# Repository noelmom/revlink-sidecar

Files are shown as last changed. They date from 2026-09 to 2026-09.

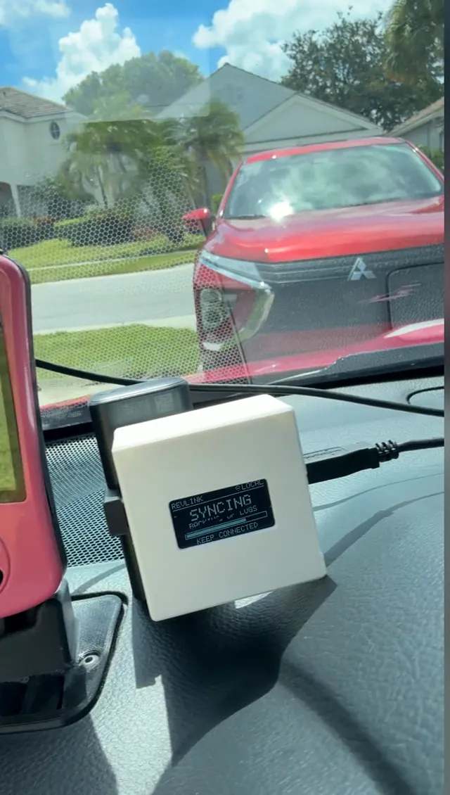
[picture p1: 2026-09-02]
web/site/assets/sidecar-sync-poster.webp

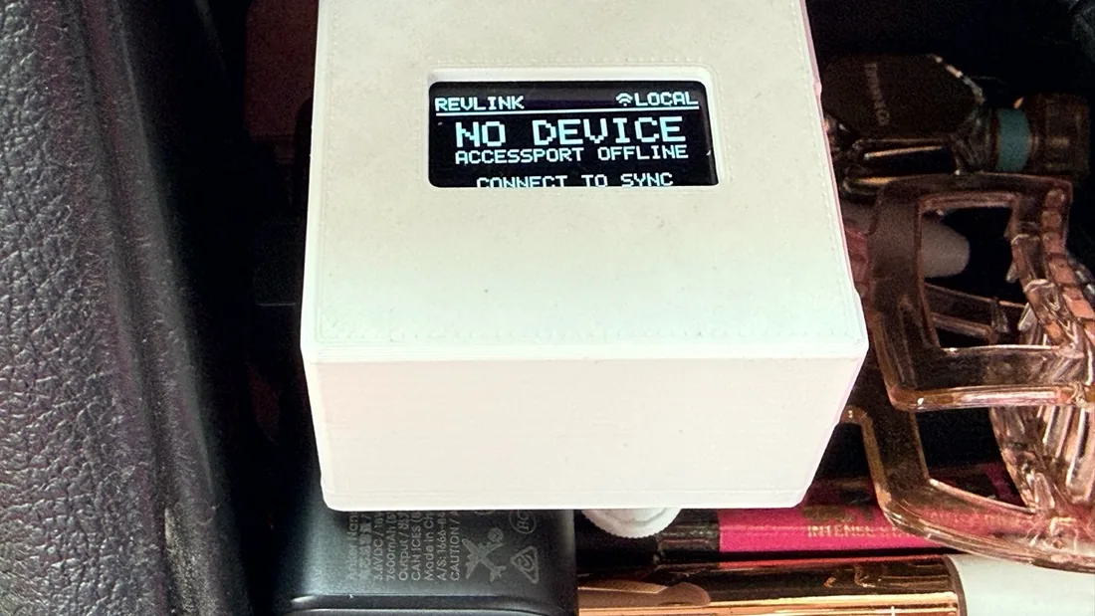
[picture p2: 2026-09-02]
web/site/assets/sidecar-oled.webp

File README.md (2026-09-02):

# RevLink Sidecar

**Use your AccessPort without a laptop.**

The COBB AccessPort stores your datalogs and maps over USB, but it only talks
to a Windows PC or a Mac. That means the moment you want to pull a log at the
track, at a meet, or in your own driveway, you need to go find a computer.

RevLink Sidecar is an ESP32-P4 that sits between the AccessPort and your
phone. Plug the AccessPort into the Sidecar, open a web page on your phone,
and your datalogs and maps are there — listed, downloadable, and graphable,
with no PC, no cloud account, and no internet connection.

Everything runs on the device. Your files land on a microSD card you own.

```
  AccessPort ──USB-A host──> ESP32-P4 Sidecar ──Wi-Fi──> your phone's browser
                                    │
                                 microSD
```

---

## What it does today

- **Automatic sync on attach.** Plug in the AccessPort and new datalogs and
  maps copy to microSD incrementally — only what changed.
- **Local web portal.** Served from the device itself. Joins your home or shop
  Wi-Fi when it can, and falls back to its own `RevLink-<id>` hotspot with a
  captive portal when it can't.
- **Datalog viewer.** Single and split views, numeric Y axes, searchable
  channels, reusable presets (Air/Fuel, Boost, Knock, Timing, Thermal),
  pointer inspection with exact values.
- **Vehicle Health.** A deterministic, local, rule-based evidence pass over
  logs you have already synced. No AI, no phone-home — it shows you the
  evidence it used.
- **Multi-device.** Keeps separate datasets per AccessPort, so a shop can
  service several cars without mixing files.
- **Stage a map without the device.** Save a `.ptm` while the AccessPort is
  unplugged; it is pinned to that car and survives a power cycle. Transfer it
  by hand when the device is next connected, or let it apply automatically
  after the next sync — that part is off until you turn it on.
- **Direct download and share.** Pull individual CSVs, or hand them to your
  phone's native share sheet.
- **OLED status.** Optional 1.3" SH1106 shows attach, sync, and network state
  at a glance.
- **Offline by design.** No account, no telemetry, no cloud dependency.

## What it deliberately does not do

This project reads and writes *files*. It is not a tuning tool.

- **No ECU flashing.** Not now, not planned.
- **No real-time tuning or live ECU writes.**
- **Map writes arrive locked** and stay off until you enable them. Copying a
  `.ptm` onto the AccessPort's storage is not the same as installing it — that
  remains a deliberate action on the AccessPort itself.
- **File deletion arrives locked too**, behind a *separate* switch from map
  writes — agreeing to one is never agreeing to the other. Only files directly
  inside `maps/` and `datalog/`, and there is no undo. See
  [SAFETY.md](SAFETY.md).
- **No public internet exposure.** The portal has no transport encryption and
  is meant for a trusted local network.

## Using it

One button does everything. On the Waveshare board it is `BOOT`; on the printed
case it is the left side button.

| Gesture | What it does |
| --- | --- |
| Double-press | Shows how to reach the portal — a Wi-Fi QR code when the Sidecar is running its own hotspot, or its `revlink-<id>.local` address when it has joined your network |
| Press again | Dismisses it |
| Hold 2 seconds | Safe shutdown: cancels work, unmounts the card, sleeps. `RST` or a power cycle wakes it |
| Two double-presses within 20 s | Authorises formatting a card that responded but would not mount — see [POWER_MANAGEMENT.md](docs/POWER_MANAGEMENT.md) |

The display gestures need the optional OLED. Everything else works without one.

## Hardware

| Part | Notes |
| --- | --- |
| Waveshare **ESP32-P4-NANO** | Primary target. USB-A OTG high-speed host, 16 MB flash, 32 MB PSRAM. [Buy][aff-nano] |
| Waveshare **ESP32-P4-WIFI6-DEV-KIT** (SKU 32054) | Supported, but build it yourself — no image is published for it. P4 revision 3.x silicon vs the Nano's 1.x, and the binaries are not interchangeable. |
| microSD card | Stores all synced files. Any capacity. [Buy][aff-sd] |
| 1.3" SH1106 OLED (optional) | SPI, not I2C. Status display. [Buy][aff-oled] |
| USB-C power bank | The reference build runs off an Anker Nano ([buy][aff-bank]). The Sidecar powers the AccessPort as a USB host, so give it a real 5 V supply — never source VBUS from a GPIO. |
| 3D-printed enclosure | [`hardware/nano-enclosure/`](hardware/nano-enclosure/) |

[aff-nano]: https://amzn.to/462r0q8
[aff-sd]: https://amzn.to/4h381C1
[aff-oled]: https://amzn.to/46BiJJQ
[aff-bank]: https://amzn.to/4gxIFfp

> **Affiliate disclosure.** The **Buy** links above are Amazon affiliate links.
> As an Amazon Associate I earn from qualifying purchases, at no extra cost to
> you. They point at the exact parts this was built and tested on, which is why
> they are here rather than a generic search. Buy them anywhere you like —
> nothing in this project depends on where the hardware came from.

**Why ESP32-P4 and not an S3?** The S3's native USB host is full-speed only,
and the AccessPort's 512-byte bulk endpoints require high speed. The S3 was
tried and retired — the full write-up is in
[`docs/ESP32S3_USB_POWER_BRINGUP.md`](docs/ESP32S3_USB_POWER_BRINGUP.md).

> [!NOTE]
> **Enclosure status.** This geometry has been printed and assembled — it is
> the case in the photos on [revlinkgarage.com](https://revlinkgarage.com/).
> The lid conceals the Ethernet jack, closes the
> donor case's switch slot and spare USB-A opening, and adds the centered OLED
> window plus two guided side buttons for RST and BOOT.
>
> One known refinement remains: the lid has **no internal mounting posts for
> the OLED**, so the display is retained by the window edge and its wiring.
> Adding four posts is a good first contribution — see
> [`hardware/nano-enclosure/tools/`](hardware/nano-enclosure/tools/) for a
> dependency-free way to verify a revision actually changed what you think it
> changed.

## Install

**Easiest — flash from your browser:
[revlinkgarage.com/flash](https://revlinkgarage.com/flash/)**

Open it in Chrome or Edge, plug the board in over USB-C, and click Flash. No
toolchain, no command line. It reads the board's silicon revision first and refuses to write an
image built for the other P4 variant.

The published image can read your AccessPort and, once you turn it on, copy a
`.ptm` map file back onto it. Writing arrives **locked**: you enable it in
Settings, only `maps/*.ptm` is accepted, and every write is read back and
checked against its SHA-256.

It can also delete files from `maps/` and `datalog/`, so a full AccessPort can
be cleared without a computer. That is a second switch, locked by default and
separate from writes, with no undo.

See [`web/flash/`](web/flash/) to host the page yourself.

## Build

Requires **ESP-IDF v6.0.2**, pinned in
[`firmware/esp32p4/idf-version.txt`](firmware/esp32p4/idf-version.txt).

```bash
source "$HOME/.espressif/frameworks/esp-idf-v6.0.2/export.sh"
```

Nano (P4 revision 1.x) — build in its own directory:

```bash
NANO_BUILD="$PWD/firmware/esp32p4/build-nano"
idf.py -C firmware/esp32p4 -B "$NANO_BUILD" \
  -D "SDKCONFIG=$NANO_BUILD/sdkconfig" \
  -D 'SDKCONFIG_DEFAULTS=sdkconfig.defaults;sdkconfig.oled.defaults;sdkconfig.wifi-scan.defaults;sdkconfig.wifi-join.defaults;sdkconfig.network-runtime.defaults;sdkconfig.onboarding.defaults;sdkconfig.nano.defaults' \
  set-target esp32p4 build
```

Do not flash a Dev Kit image onto a Nano. Full build and flash notes:
[`firmware/esp32p4/README.md`](firmware/esp32p4/README.md).

## Tests

The protocol, sync, storage, network, power, and safety logic are all built as
plain C11 with no ESP-IDF dependency, so they run on your laptop:

```bash
./scripts/ci-local.sh
```

That runs 19 host suites, 7 Node-based portal tests, the web flasher tests,
and the enclosure geometry baseline — about 20 seconds, and it needs only a C
compiler. If you don't have CMake, the script compiles the tests directly with
the same flags.

Add `--full` to also build the firmware three ways: writes enabled, deletion
compiled in, and writes compiled out. Building every configuration is what
catches code that only compiles under one of them. That needs ESP-IDF v6.0.2
plus CMake and Ninja.

```bash
./scripts/ci-local.sh --full
```

## Repository layout

```
firmware/
  esp32p4/          ESP32-P4 application, portal, storage, Kconfig, sdkconfig overlays
  components/       Platform-neutral C components (protocol, sync, network, status, …)
  test/             Host-side test suites — no hardware required
hardware/
  nano-enclosure/   3D-printable case: STL/3MF, source geometry, print notes
docs/               Architecture, safety model, networking, storage, bring-up
```

## Documentation

| Document | What it covers |
| --- | --- |
| [FIRMWARE_ARCHITECTURE.md](docs/FIRMWARE_ARCHITECTURE.md) | Component boundaries, device lifecycle, stable contracts |
| [SINGLE_ACCESSPORT_SAFETY.md](docs/SINGLE_ACCESSPORT_SAFETY.md) | Why two attached AccessPorts fail closed instead of guessing |
| [MAP_WRITE_ACCEPTANCE.md](docs/MAP_WRITE_ACCEPTANCE.md) | The gated round-trip procedure for map writes |
| [FILE_DELETE.md](docs/FILE_DELETE.md) | Removing a file from the AccessPort, and why it is gated apart from writes |
| [ACCEPTANCE_LOG.md](docs/ACCEPTANCE_LOG.md) | Dated bench records for the ESP32-P4 target. History, not current state |
| [FIRMWARE_UPDATE.md](docs/FIRMWARE_UPDATE.md) | How firmware gets onto the board, and why there is no OTA |
| [POWER_MANAGEMENT.md](docs/POWER_MANAGEMENT.md) | BOOT-button behaviour, safe shutdown, and deep sleep |
| [WIFI_BRINGUP.md](docs/WIFI_BRINGUP.md) | The ESP32-C6 radio link over SDIO, and what it took to bring up |
| [OLED_BRINGUP.md](docs/OLED_BRINGUP.md) | SH1106 wiring and the status screens |
| [ACCESSPORT_TIME_METADATA.md](docs/ACCESSPORT_TIME_METADATA.md) | What the AccessPort's timestamps mean, and what RevLink records instead |
| [ESP32S3_USB_POWER_BRINGUP.md](docs/ESP32S3_USB_POWER_BRINGUP.md) | Why the ESP32-S3 was retired: full-speed USB cannot do 512-byte bulk |
| [ESP32P4_DEMO.md](docs/ESP32P4_DEMO.md) | Runbook for demonstrating the Sidecar |
| [OPERATIONAL_LOGGING.md](docs/OPERATIONAL_LOGGING.md) | What is logged, what is not, and the two audit logs that ship |
| [STAGED_MAPS.md](docs/STAGED_MAPS.md) | Uploading a map with no AccessPort attached, and applying it on the next sync |
| [PRODUCT_NETWORKING.md](docs/PRODUCT_NETWORKING.md) | Client-first Wi-Fi with fallback hotspot and captive portal |
| [ACCESSPORT_STORAGE_BEHAVIOR.md](docs/ACCESSPORT_STORAGE_BEHAVIOR.md) | How the device's filesystem actually behaves |
| [SUPPORTED_ACCESSPORTS.md](docs/SUPPORTED_ACCESSPORTS.md) | Which hardware is verified, and how families are identified |
| [ACCESSPORT_CATALOG.md](docs/ACCESSPORT_CATALOG.md) | The part-number table: what it is, where it comes from, how to add to it |
| [VEHICLE_HEALTH.md](docs/VEHICLE_HEALTH.md) | The deterministic diagnostic layer |
| [SIDECAR_SD_BACKUP.md](docs/SIDECAR_SD_BACKUP.md) | Backing up and restoring the card |

## Status

Actively developed, and in regular use on a real car. Read-only sync (listing,
incremental download, checksum verification, atomic microSD publication) has
been accepted on real hardware, and so has writing: maps have been transferred
to an attached AccessPort many times, each verified by read-back, including
unattended transfers after a sync. Deletion is accepted too.

All three ship in the published image. Writes and deletes remain **gated** —
not because the paths are unproven, but because they are the owner's decision
to make. See [SAFETY.md](SAFETY.md) for exactly what is and is not proven.

## Contributing

Issues and PRs welcome — especially enclosure revisions, additional AccessPort
families, and portal UX. Please read [CONTRIBUTING.md](CONTRIBUTING.md) and
[SAFETY.md](SAFETY.md) first; this project touches hardware people depend on,
and the safety gates are not incidental.

## License

- Code (`firmware/`, scripts): **Apache-2.0** — [LICENSE](LICENSE)
- Hardware (`hardware/`): **CC BY-SA 4.0** — [LICENSE-hardware](LICENSE-hardware)

## Legal

RevLink Sidecar is an independent, unofficial project. It is not affiliated
with, endorsed by, or sponsored by COBB Tuning. "COBB" and "AccessPORT" are
trademarks of their respective owners and are used here only to identify the
hardware this project interoperates with. See [NOTICE](NOTICE).

Modifying your vehicle may affect its warranty, emissions compliance, and
legal road status in your jurisdiction. That is your responsibility. This
software is provided without warranty of any kind.

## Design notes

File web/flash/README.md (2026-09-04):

# Web flasher

A static page that flashes a RevLink Sidecar release over Web Serial. No
build step — plain HTML, CSS, and ES modules. Serve the directory over HTTPS
(or `localhost`) and it works.

```bash
python3 -m http.server 8777 --directory web/flash
```

It is self-contained and origin-relative, so the same directory can be
published on GitHub Pages, dropped onto revlinkgarage.com, or embedded in an
iframe.

## Layout

```
index.html                      markup and copy
style.css                       styling, light and dark
flash.js                        Web Serial + esptool-js driver
gate.js                         board-compatibility gate (no browser deps)
gate.test.mjs                   tests for the gate and the release manifest
vendor/esptool-js-0.6.1.js      vendored flashing library (Apache-2.0)
firmware/<release>/             binaries + manifest.json + SHA256SUMS
```

## Why the library is vendored

`esptool-js` is committed here rather than loaded from a CDN. This page writes
to people's hardware; a CDN that can substitute the script can substitute what
gets written. Vendoring also means the page keeps working offline and when a
CDN is blocked.

Upgrading it is deliberate: replace the file, bump the import in `flash.js`,
record the new SHA-256 below, and re-test against a real board.

```
esptool-js 0.6.1
sha256  ef7d5a237d3f273ecf546bcee65dddad90bd82cf02f22a980d1537e0cd79a152
```

## The board gate

The ESP32-P4-NANO and the ESP32-P4-WIFI6-DEV-KIT both report as `ESP32-P4`
but use pre-v3 and v3+ silicon, which ESP-IDF treats as mutually incompatible
firmware targets. `gate.js` reads the silicon revision and **refuses** a
mismatch before writing anything.

It fails closed. An unreadable revision, an unexpected chip family, or a
missing manifest field all refuse; only a positive match enables the button.
`gate.test.mjs` covers each case, and runs in `scripts/ci-local.sh`.

## Integrity

Every part is fetched, size-checked, and SHA-256 verified against
`manifest.json` before a byte reaches the board. A truncated download or a
tampered mirror fails before flashing, not halfway through it.

`gate.test.mjs` additionally verifies that the published binaries match their
recorded digests, that flash regions do not overlap, and that the image agrees
with what the manifest claims about device writes and deletes — by looking for
the corresponding log strings and NVS keys in the binary rather than trusting
the manifest's own flags, in either direction. A manifest that *under*-claims
fails too: people decide what to install from it.

It also asserts the shipping posture those flags imply — that a write-capable
image still declares consent locked at startup, and that a delete-capable one
carries its own separate consent key rather than riding on the write flag.

## Releases are immutable

```
releases.json                    {"current": "v0.2.6-nano"}
firmware/v0.2.6-nano/            binaries + manifest.json + SHA256SUMS
firmware/v0.2.5-nano/            the previous one, still reachable
```

A published release directory is never rewritten. A version string has to name
one set of bytes: if two different binaries both call themselves 0.2.0, a bug
report against 0.2.0 cannot be resolved, and someone comparing behaviour
between two boards has nothing to compare. Version 0.2.0 was overwritten
repeatedly while this repository was being built and was removed rather than
left as a false reference.

Publishing therefore *adds* a directory and moves the pointer in
`releases.json`. The page and the tests both read that pointer, so nothing has
to be edited in two places, and older releases stay reachable for anyone who
needs to go back to a build that worked.

`gate.test.mjs` enforces the parts of this that can be checked: the manifest
version must match the directory it lives in, and every release named in
`releases.json` must exist with digests that verify.

## Cutting a new release

```bash
# 1. Bump firmware/esp32p4/version.txt. Every published build gets its own
#    version; commits between publishes do not need one.
# 2. Build the profile you intend to publish.
source "$HOME/.espressif/frameworks/esp-idf-v6.0.2/export.sh"
B="$PWD/build-release/nano"
D='sdkconfig.defaults;sdkconfig.oled.defaults;sdkconfig.wifi-scan.defaults;sdkconfig.wifi-join.defaults;sdkconfig.network-runtime.defaults;sdkconfig.onboarding.defaults;sdkconfig.nano.defaults'
idf.py -C firmware/esp32p4 -B "$B" \
  -D "SDKCONFIG=$B/sdkconfig" -D "SDKCONFIG_DEFAULTS=$D" \
  set-target esp32p4 build

# 3. Copy the four artefacts into a NEW web/flash/firmware/<version>-<profile>/
#    as bootloader.bin, partition-table.bin, ota-data-initial.bin and
#    revlink-sidecar.bin. Never into an existing one.
# 4. Write its manifest.json and SHA256SUMS.
# 5. Add it to releases.json and set "current" to it.
# 6. Run ./scripts/ci-local.sh — the manifest, version and digest assertions
#    must pass.
# 7. Flash a real board before announcing it.
# 8. Re-check the docs against what you just flashed. See below.
# 9. Open a PR and MERGE IT WITH A MERGE COMMIT, not a squash. See below.
# 10. Tag the build commit, then cut a GitHub Release pointing at the release
#     directory on main.
```

### Re-check the docs against what you just built

Every sentence in the docs saying the firmware cannot do something is a claim
with an expiry date. Three have been wrong in public: the landing page said
writing maps was unproven on hardware while it was in daily use, `SAFETY.md`
said consent re-locks every boot when it persists in NVS, and
`WIFI_BRINGUP.md` listed a shipped network stack as future work.

This finds the sentences worth re-reading. It returns a short list, not a wall:

```bash
grep -rniE "not yet|has not been|have not been|is not implemented|\
remains unimplemented|not proven|future work|remaining work|\
not in the published|does not yet" \
  --include="*.md" --include="*.html" docs/ web/site/ *.md
```

Confirm each hit is still true of the build in the release directory, and fix
what is not in the same PR.

Check them against the tree or the binary, **never against another doc**. The
landing page's false claim was inherited from `SAFETY.md`, so a single stale
sentence propagated outward into the most public surface the project has.

Both directions matter, but they are not equally bad. Understating what
shipped is embarrassing. Overstating a safety property — or failing to notice
one has regressed — is not, and that is the direction this check exists for.

### Merge the release PR, do not squash it

`main` is protected, so a release goes through a pull request. Merge it with a
**merge commit**.

The binary embeds the commit it was built from — `CMakeLists.txt` resolves it
at configure time into `REVLINK_GIT_COMMIT`, it is what the portal footer
shows, and it is what `manifest.json` records as the provenance for those
bytes. A squash mints a new hash and discards the one that was built, so the
manifest ends up naming a commit that never reaches `main`. The release
directory then cannot be traced back to anything, which is the entire property
it exists to provide.

After merging, confirm it survived:

```bash
git merge-base --is-ancestor <build-commit> main && echo ok
```

### Tag the build commit, not the publish commit

```bash
git tag -a v0.2.6 <build-commit> -m "RevLink Sidecar 0.2.6 (v0.2.6-nano)"
git push origin v0.2.6
```

The tag names the commit whose source reproduces the published bytes. It
deliberately does **not** contain the release directory, which is added by the
commit after it — so a GitHub Release body must link the directory on `main`:

```
https://github.com/noelmom/revlink-sidecar/tree/main/web/flash/firmware/v0.2.6-nano
```

not at the tag, where it 404s. Release directories are immutable, so a link to
`main` is stable forever.

It is tempting to fix that by moving the tag onto the publish commit instead.
Do not. For 0.2.2 the embedded `portal/index.html` was corrected between the
build and the publish commit, so the publish commit does not rebuild the bytes
that were shipped. Tagging it would trade a broken link for a false provenance
claim, which is worse.

Offsets for the current partition table:

| Part | Offset |
| --- | --- |
| `bootloader.bin` | `0x2000` |
| `partition-table.bin` | `0x8000` |
| `ota-data-initial.bin` | `0xF000` |
| `revlink-sidecar.bin` | `0x20000` |

## Browser support

Web Serial is Chromium-only — Chrome, Edge, Opera, Arc, Brave. Safari and
Firefox do not implement it, and the page says so plainly instead of failing
mysteriously.

## Driver support

The Nano's programming console runs through an onboard WCH USB-serial bridge
(`1a86:55d3`). No driver is needed: confirmed on a clean Windows 11 machine and
on macOS, where the board enumerates on its own and flashes without anything
being installed first.

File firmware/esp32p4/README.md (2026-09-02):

# RevLink ESP32-P4 firmware

This target is the consumer-product hardware acceptance path for the Waveshare
`ESP32-P4-WIFI6-DEV-KIT` (SKU 32054) and `ESP32-P4-NANO`. They share the same
RevLink application and peripheral adapters but require separate binary builds
because the Dev Kit uses P4 revision 3.x silicon and the current Nano uses P4
revision 1.x silicon. Only the Nano has a published image; build the Dev Kit
yourself.

## Pinned environment

- Target: `esp32p4`
- ESP-IDF: `v6.0.2`
- Flash: 16 MB
- Stacked PSRAM: 32 MB, hex mode at 200 MHz
- Programming console: Type-C UART through the onboard WCH bridge
- AccessPort port: USB-A OTG 2.0 high-speed host, with the board's OTG jumper
  set to `HOST`

### ESP32-P4-NANO build

The Nano preserves the accepted RevLink prototype wiring:

- OLED: SPI2, CLK GPIO23, MOSI GPIO22, CS GPIO21, D/C GPIO20, RESET GPIO2;
- microSD: GPIO39 through GPIO44;
- ESP32-C6 Wi-Fi/BT link: SDIO GPIO14 through GPIO19, reset GPIO54; and
- AccessPort: onboard USB-A OTG 2.0 high-speed host.

The Nano overlay enables the SH1106 controller's 180-degree orientation for
the compact enclosure. Rendering stays in the shared framebuffer; the
board-specific overlay changes only the controller's segment and COM scan
directions.

Do not flash the Dev Kit's revision-3.x image onto the Nano. Build the Nano in
its own clean directory with the revision-1.x overlay:

```sh
source "$HOME/.espressif/frameworks/esp-idf-v6.0.2/export.sh"
NANO_BUILD="$PWD/firmware/esp32p4/build-nano"
idf.py -C firmware/esp32p4 \
  -B "$NANO_BUILD" \
  -D "SDKCONFIG=$NANO_BUILD/sdkconfig" \
  -D 'SDKCONFIG_DEFAULTS=sdkconfig.defaults;sdkconfig.oled.defaults;sdkconfig.wifi-scan.defaults;sdkconfig.wifi-join.defaults;sdkconfig.network-runtime.defaults;sdkconfig.onboarding.defaults;sdkconfig.nano.defaults' \
  set-target esp32p4 build
```

## Normal runtime and safety defaults

The normal build powers and enumerates the proven high-speed USB host, but it
does not start a file session unless the saved auto-sync preference is enabled
or the application receives an explicit manual request:

- `CONFIG_REVLINK_USB_ROOT_PORT_POWER` is enabled.
- `CONFIG_REVLINK_RUNTIME_SYNC` is enabled.
- `CONFIG_REVLINK_SYNC_AUTO_ON_ATTACH_DEFAULT` is disabled.
- `CONFIG_REVLINK_USB_INTERFACE_CLAIM_ACCEPTANCE` is disabled.
- `CONFIG_REVLINK_USB_ROOT_LIST_ACCEPTANCE` is disabled.
- `CONFIG_REVLINK_USB_DOWNLOAD_ACCEPTANCE` is disabled.
- `CONFIG_REVLINK_USB_INCREMENTAL_SYNC_ACCEPTANCE` is disabled.
- `CONFIG_REVLINK_ALLOW_DEVICE_WRITES` is enabled for guarded map transfer.
- `CONFIG_REVLINK_ALLOW_DEVICE_DELETES` is enabled in the Nano profile for
  guarded deletion inside `maps/` and `datalog/`.

The runtime coordinator exposes saved auto-sync policy, manual sync, progress
snapshots, and cooperative cancel to the embedded local API. Its bounded
read-only USB batch still permits at most four new files, 16 MiB per batch, and
8 MiB per file. A normal sync automatically opens clean continuation batches
until the complete safe inventory is verified or a batch makes no forward
progress. Guarded map transfer is available only after persistent owner
consent is enabled in Settings; new and factory-reset Sidecars default locked.
Startup-screen transfer uses the same guarded service and fixed framebuffer
target but still awaits its first live P4 write/read-back acceptance. Deletion
of files inside `maps/` and `datalog/` is compiled into the Nano profile from
0.2.2 and sits behind its own consent, separate from the write consent and
never implied by it.

The transport-neutral `revlink_control` service exposes those runtime
operations as status, auto-sync, manual-sync, and cancel commands. It returns
an immutable post-command snapshot and contains no HTTP, JSON, Wi-Fi, USB, or
storage implementation. The embedded portal's local HTTP adapter translates
requests into this contract rather than reaching into the USB stack.

The platform-neutral `revlink_usb_control` component is compiled into the P4
application and host-tested independently. The current P4 adapter does not
drive external GPIO because the isolation modules have not completed bench
bring-up. Do not assign USB control to GPIO39 through GPIO44; those pins are
reserved by the accepted microSD interface.

### Prototype status display

The optional `CONFIG_REVLINK_STATUS_OLED` adapter drives the existing
1.3-inch SH1106 SPI OLED. The screen shows the RevLink boot animation,
AccessPort availability, sync progress, recovery, completion, and actionable
fault states. Product state and copy come from the platform-neutral
`revlink_status` component; the SH1106 framebuffer and SPI transport remain a
replaceable P4 adapter.

Physical display acceptance passed on 2026-07-27: the splash and live status
rendered at the correct orientation and size while an attached AccessPort
advanced from inspection to ready state.

Use the reviewed prototype wiring in
[`OLED_BRINGUP.md`](../../docs/OLED_BRINGUP.md).
`sdkconfig.oled.defaults` is part of the shipped Nano fragment list, so the
published image includes this adapter; the panel itself is optional and the
firmware runs without one. To build the display overlay on its own:

```sh
source "$HOME/.espressif/frameworks/esp-idf-v6.0.2/export.sh"
idf.py -C firmware/esp32p4 \
  -B firmware/esp32p4/build-oled \
  -D SDKCONFIG=sdkconfig.oled \
  -D 'SDKCONFIG_DEFAULTS=sdkconfig.defaults;sdkconfig.oled.defaults' \
  set-target esp32p4 build
```

### Development UART control

The OLED bench overlay also enables `CONFIG_REVLINK_DEV_CONSOLE`. This
programming-UART adapter exercises the same transport-neutral control service
that future authenticated HTTP and BLE adapters will use:

```text
status
sync
cancel
auto on
auto off
help
```

The grammar is fixed and fail-closed. It has no command for device paths,
protocol opcodes, upload, delete, formatting, or arbitrary shell execution.
`auto on` and `auto off` update the saved automatic-sync preference; the
reviewed bench image is left with that preference off.

Live acceptance passed on 2026-07-27. A manual `sync` issued over the UART
selected the authoritative AccessPort namespace, reconciled 33 files as
verified cache hits, sent the polite subtype `0x05`, received subtype `0x35`,
and returned the re-enumerated device to `available`. A subsequent `status`
reported `completed`, progress `33/33`, auto-sync off, and writes locked. The
nonblocking console was also left idle for several seconds without prompt
repainting or interfering with enumeration.

### Development-board soft power

The Waveshare board's onboard `BOOT` button is GPIO35. After firmware boot, a
double press shows a full-screen Wi-Fi join QR when the RevLink hotspot is
active. When the Sidecar is already connected to a preferred Wi-Fi network,
the same double press shows its `revlink-<suffix>.local` browser address for
20 seconds instead. One additional short press dismisses either overlay.
The hotspot QR has a 30-second timeout and contains only the volatile
per-boot hotspot credential; generation is synchronous with the QR library's
input logging suppressed, and the payload is zeroized after its display
bitmap is captured. An active sync dismisses the URL overlay so transfer
safety status always wins.

The display also treats physical device state as newer than a terminal sync
result. Unplugging the AccessPort after a successful backup replaces
`<vehicle> / BACKUP COMPLETE / SAFE TO DISCONNECT` with
`NO DEVICE / ACCESSPORT OFFLINE / CONNECT TO SYNC`; a USB fault similarly
replaces stale completion with the attention view.

Once the read-only identity handshake has supplied the installed vehicle, the
ready view shows `<vehicle> / ACCESSPORT CONNECTED / READY TO SYNC`. Before
that authoritative identity is available, `ACCESSPORT` is used as the safe
headline fallback. The known vehicle is preserved through the expected
software re-enumeration after a clean session close, but is cleared for a
genuinely new physical attachment.

A two-second hold requests a demo-safe logical shutdown:

1. block new manual and automatic sync requests;
2. cooperatively cancel a queued or active sync and wait for a terminal state;
3. stop the logical USB root port;
4. abort any incomplete cache writer, release the selected device namespace,
   unmount the microSD card, and release its LDO; and
5. enter deep sleep.

Wake by pressing `RST` or cycling external power. `BOOT` is not configured as
a wake source on this development board.

This is a convenient prototype control, not physical power-off. The current
board cannot isolate USB D+/D- or VBUS in firmware. A properly initialized
session can return the AccessPort to Gauges by sending the polite subtype
`0x05`, receiving subtype `0x35`, and releasing the interface. An interrupted
or incomplete session may leave the AccessPort in PC mode, but a stale
read-only session has been recovered by reinitializing the complete session
and then performing the acknowledged polite close. The `revlink_usb_link`
board adapter still reports physical-isolation capabilities explicitly so an
optional future data/VBUS switch can be evaluated as defense in depth rather
than as the normal session-close path or a firmware dependency.

Idle-device live acceptance passed on 2026-07-27. With an enumerated
AccessPort and no active sync, the two-second hold blocked new work, disabled
the logical root port, produced a clean USB detach, unmounted and powered down
the microSD card, and entered deep sleep. Active-sync cancellation acceptance
remains pending.

## Architecture

The P4 firmware consumes platform-neutral components from
`firmware/components/`.
The protocol, lifecycle state machine, safety policy, and application
orchestration have no ESP-IDF dependency. The ESP-IDF USB host is an adapter
that emits normalized lifecycle events, and this target's `main/` directory is
the sole active firmware composition root plus the P4 SDMMC adapter.

See [`docs/FIRMWARE_ARCHITECTURE.md`](../../docs/FIRMWARE_ARCHITECTURE.md) for
the dependency rules and extension workflow.

## Build and flash

```sh
source "$HOME/.espressif/frameworks/esp-idf-v6.0.2/export.sh"
idf.py -C firmware/esp32p4 set-target esp32p4
idf.py -C firmware/esp32p4 build
idf.py -C firmware/esp32p4 \
  -p <your serial port> flash monitor
```

The first USB milestone is descriptor-only enumeration of VID/PID
`1a84:0121` at high speed with interface `0`, bulk OUT `0x03`, bulk IN `0x82`,
and 512-byte maximum packets. No proprietary request is permitted before that
gate passes.

## Hardware acceptance records

The dated bench records for this target — USB high-speed bring-up, microSD
coexistence with the onboard radio, incremental sync, multi-device safety,
session close, and guarded map transfer — are in
[`../../docs/ACCEPTANCE_LOG.md`](../../docs/ACCEPTANCE_LOG.md). They are
historical entries, not a description of the current build.

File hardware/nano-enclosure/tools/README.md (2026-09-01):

# Enclosure validation tools

## `stl_inspect.py`

Reports triangle count, bounding box, watertightness, and **genus** for a
binary STL. No dependencies — plain Python 3.

Genus is the useful number: it counts through-holes in a closed shell. Use it
to prove that a revision actually closed an opening rather than just
re-exporting the same geometry.

```bash
python3 stl_inspect.py ../enclosure-print/print-package/*.stl
```

Current baseline:

| Part | Genus | Meaning |
| --- | --- | --- |
| `source/esp32-p4-nano-bottom.stl` (donor) | 5 | Original case bottom |
| `01-…-nano-bottom.stl` (shipped) | 5 | Unchanged from donor |
| `source/esp32-p4-nano-top-solid.stl` (donor) | 6 | Original case lid |
| `02-…-top-oled-usbc-controls.stl` (shipped) | 3 | Revised lid — three openings closed |

### Measured bottom-shell openings

Sliced at z = 1.0 mm (the shipped `01` bottom, which is topologically
identical to the donor part):

| Wall | Span | Width |
| --- | --- | --- |
| Y− (`y = -2.5`) | `x` 3.0 → 18.0 | 15.0 mm |
| Y+ (`y = 52.5`) | `x` 19.7 → 27.1 | 7.4 mm |
| Y+ (`y = 52.5`) | `x` 32.0 → 40.0 | 8.0 mm |

The bottom is carried over from the donor case unchanged; the revised lid is
what conceals the Ethernet jack in the assembled enclosure. If you close or
reshape any of these bottom openings, the genus should drop accordingly —
that is the check this tool exists for.

Note that genus cannot see solid internal additions: adding the four OLED
mounting posts will raise the triangle count while leaving genus unchanged.
Check those visually in the slicer and against the physical display PCB.

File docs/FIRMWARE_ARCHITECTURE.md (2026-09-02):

# RevLink firmware architecture

The consumer firmware uses a layered, ports-and-adapters architecture. Board
SDKs and peripherals are implementation details at the edge; product rules
remain ordinary C that can run in host tests.

## Dependency direction

```text
esp32p4/main                         composition root
        |
        v
revlink_application   P4 hardware adapters
        | \ \          |-- accessport_usb (ESP-IDF USB Host)
        |  \ \         |-- P4 SD storage
        |   \ \        |-- P4 USB link control
        |    \ \       |-- P4 soft-power task
        |     \ \      |-- P4 SH1106 status display
        |      \ \     `-- P4 development UART
        v      v v
revlink_core  revlink_sync  accessport_protocol  revlink_power
                      \                 /
                       revlink_status  revlink_cli
```

Dependencies point inward. A core or application component must never include
ESP-IDF, FreeRTOS, USB, SDMMC, Wi-Fi, or board headers. An adapter may depend
on an inward contract and its platform SDK. Board `main/` code only selects
implementations, supplies configuration, and connects event callbacks.

## Current components

| Component | Responsibility | Platform dependency |
| --- | --- | --- |
| `accessport_protocol` | Capture-verified framing, parsing, checksums, and upload target validation | None |
| `accessport_catalog` | Exact-match supported-part catalog and family classification, without transport or feature side effects | None |
| `revlink_core` | Device lifecycle state machine and centralized operation authorization | None |
| `revlink_sync` | Incremental manifests/history plus the runtime sync coordinator and progress model | None |
| `revlink_power` | Debounce, long-press timing, and one-shot shutdown intent | None |
| `revlink_network` | Client-first/fallback-hotspot policy, sticky reconnect, time budgets, and transfer lock | None |
| `revlink_credentials` | Bounded Wi-Fi identity/password validation and explicit zeroization | None |
| `revlink_identity` | Persistent random Sidecar ID, MAC-derived local naming, and bounded collision suffixes | None |
| `revlink_staged_map` | Staged-map record codec and the pure decision function for applying one after a sync | None |
| `revlink_storage_recovery` | Guarded recovery state machine for a card that responds but does not mount | None |
| `revlink_oled_render` | 5x7 font, framebuffer primitives, and the boot splash layout, renderable on a host | None |
| `revlink_captive_dns` | Bounded DNS question parser and local IPv4 response encoder | None |
| `revlink_time` | Trusted/untrusted wall-clock classification and portable timestamp conversion | None |
| `revlink_update` | Bounded post-boot health decision, blocker reporting, and terminal ready/timeout/safety rejection | None |
| `revlink_usb_control` | Transport-neutral logical/electrical USB-link capabilities and safe control contract | None |
| `revlink_application` | Product-level initialization, protocol self-test, device/sync orchestration, and auto-sync policy | None |
| `revlink_control` | Transport-neutral local control commands and immutable status responses | None |
| `revlink_status` | Deterministic user-facing display state, progress, and copy derived from device/sync snapshots | None |
| `revlink_cli` | Fixed development command grammar and response formatting over the control contract | None |
| `accessport_usb` | ESP-IDF USB enumeration and normalized lifecycle events | ESP-IDF |
| `esp32p4/main/revlink_sd_storage` | P4 board SDMMC mount and accepted card layout | ESP-IDF/P4 |
| `esp32p4/main/revlink_usb_link` | Board-specific logical or physical AccessPort-link isolation | ESP-IDF/board |
| `esp32p4/main/revlink_soft_power` | GPIO polling and safe shutdown sequencing | ESP-IDF/P4 |
| `esp32p4/main/revlink_status_oled` | Optional SH1106 SPI framebuffer and status task | ESP-IDF/P4 |
| `esp32p4/main/revlink_dev_console` | Optional nonblocking programming-UART adapter for `revlink_cli` | ESP-IDF/P4 |
| `esp32p4/main/revlink_wifi_radio` | Bounded onboard ESP32-C6 acceptance adapter and identity-free radio snapshot | ESP-IDF/P4/ESP-Hosted |
| `esp32p4/main/revlink_network_runtime` | P4/C6 composition adapter for coordinator actions, RAM credentials, and transfer events | ESP-IDF/P4/ESP-Hosted |
| `esp32p4/main/revlink_onboarding` | Local HTTP setup, captive DNS/probes, mDNS, and delayed station transition | ESP-IDF/P4 |
| `esp32p4/main/revlink_portal` | Embedded product portal plus bounded status, inventory, cache streaming, notes, sync, cancel, and auto-sync HTTP adapters | ESP-IDF/P4 |
| board `main` | Hardware acceptance and dependency composition | Target board |

ESP32-P4 is the only active consumer-firmware target. Platform-neutral
components live in `firmware/components/`, and their host tests live in
`firmware/test/`. The former ESP32-S3 feasibility target is archived evidence
of the USB full-speed limitation; it is not built, maintained, or considered
when changing P4 contracts.

## Embedded product portal

The ESP32-P4 serves the product UI directly from firmware. It does not proxy
the laboratory application and does not require another computer after the
firmware is flashed. The current portal includes Dashboard, Datalogs, Maps,
Images, Device, Vehicle Health Beta, and Settings views plus a compact
five-item mobile navigation model.

The browser receives immutable cache projections and a deliberately small set
of bounded control/write adapters:

```text
GET  /api/portal/status
GET  /api/portal/devices
GET  /api/portal/files
GET  /api/portal/file?digest=<64-hex-sha256>
GET  /api/portal/backup
POST /api/portal/backup/preview
POST /api/portal/backup/restore
POST /api/portal/device/select
POST /api/portal/notes
POST /api/portal/log-map
POST /api/portal/sync
POST /api/portal/sync/cancel
POST /api/portal/auto-sync
POST /api/portal/time
POST /api/portal/writes
POST /api/portal/deletes
POST /api/portal/file/delete
POST /api/portal/maps/stage
POST /api/portal/maps/apply
POST /api/portal/maps/auto-apply
POST /api/portal/maps/discard
GET/POST /api/portal/startup/profiles
GET  /api/portal/startup/profile?id=<bounded-profile-id>
POST /api/portal/startup/apply
```

Map and startup-screen write routes remain inert until the compiled
administrator capability, persistent owner consent, one-device topology,
identity pin, exact target validator, and operation-specific confirmation all
agree. Deletion is exposed the same way, through `/api/portal/file/delete`
and `/api/portal/deletes`, behind its own consent.

`status.attachedAccessPort` is the live, read-only identity of the single
physically attached unit. `status.accessPort` is the independently selected
cached dataset retained for compatibility with the inventory projection. The
portal exposes this distinction as a global **Viewing data from** control:
switching it changes only the offline microSD projection and never redirects a
USB transaction, changes the OLED's connected-device identity, or writes to an
AccessPort.

`GET /api/portal/devices` scans only valid device namespaces whose stored
identity re-derives to the directory key. `POST /api/portal/device/select`
accepts one bounded key, requires the portal request header, and refuses to
switch while USB or synchronization work is active. The selector is responsive
and remains available on every product view, so mobile users do not need to
return to Dashboard to inspect another AccessPort's logs or maps.

The file route never accepts a path or filename. It resolves an exact digest
from the current portal snapshot, derives the object path from the selected
device namespace and known collection, then verifies the object is a regular
file with the manifest size before streaming it through a 4 KiB buffer.
Immutable objects remain valid if a later sync updates the current manifest.
Gzip-compressed datalogs retain their stored bytes and are served with
`Content-Encoding: gzip`, allowing the browser to parse the CSV without a
second decompression implementation in firmware.

The Datalogs and Maps libraries use Initial sync as their primary chronology.
Filename wrap and reuse therefore do not corrupt newest/oldest ordering.
Downloads are direct files rather than ZIP archives, and the selection bar
caps one user action at five files to keep mobile behavior predictable.
Notes remain version-scoped by SHA-256 on microSD.

The embedded log viewer parses quoted CSV locally and never sends vehicle data
off-device. It provides:

- Single and Split views;
- real numeric values and units rather than percentage normalization;
- shared-value and per-channel Y-axis modes;
- graph headroom above and below observed extrema;
- searchable channels and reusable browser-local profiles;
- Air/Fuel, Boost, Knock/Roughness, Timing, and Thermal split presets;
- pointer inspection with exact values;
- direct CSV download; and
- native OS sharing of up to five individual CSV attachments with a prepared
  subject/message and a download-plus-mailto compatibility fallback; and
- print-to-PDF using the browser's native print path.

Vehicle Health, guarded map/startup-screen writes, and native mail handoff are
local portal capabilities. Full in-browser email composition, Sidecar-hosted
delivery, accounts, share links, cloud sync, and AI analysis remain separate
product capabilities. Their absence must not cause the embedded portal to
imply that a remote service is available.

Account entitlements and billing policy do not belong in firmware. If an
optional hosted layer is ever added, a registered Sidecar may consume only a
signed, expiring capability snapshot with a bounded offline grace period. It
must never receive billing-provider identifiers, and local synchronization,
owned-data access, and export must keep working when no network is reachable.

## Stable contracts

The USB adapter reports `revlink_device_event_t`; it does not expose ESP-IDF
descriptor structures to the application. The core converts those events into
the deterministic lifecycle:

```text
stopped -> waiting -> inspecting -> available
                                     |       ^
                                     v       |
                                session-active
```

Detach returns an inspected or active device to `waiting`. Platform failures
enter `faulted`. Invalid transitions are rejected rather than guessed.

Before beta, the lifecycle must add a first-class `conflict` state for two or
more simultaneously live, accepted AccessPorts:

```text
waiting -> inspecting -> available
              |             |
              `-> conflict <-'
```

`conflict` blocks every device operation in both the application authorization
gate and USB adapter. The consumer UI never chooses between devices. The
current P4 adapter enumerates multiple addresses but its request loop still
selects the first accepted candidate, so this is an open safety gate rather
than an accepted capability. Transaction pinning, polite-re-enumeration
handling, recovery semantics, and the test matrix are defined in
[`SINGLE_ACCESSPORT_SAFETY.md`](SINGLE_ACCESSPORT_SAFETY.md).

`revlink_safety_policy_authorize()` is the mandatory operation gate.
Discovery and reads are allowed. Map writes, startup-screen writes, and device
deletes are denied by default. A transport implementation must not bypass this
application-layer decision even if it can physically submit a USB transfer.

## Channel separation

Do not create one oversized "AccessPort manager." Keep these channels
independent behind their own ports:

- file transactions on high-speed `0x03` OUT / `0x82` IN;
- live telemetry research on `0x02` OUT / `0x81` IN;
- local microSD repositories and manifests;
- Wi-Fi/BLE provisioning and connectivity;
- HTTP/API presentation;
- OTA and recovery;
- display/status output.

This prevents an experimental live-data decoder, a new storage backend, or a
different radio from destabilizing proven file synchronization.

### Supported-device classification

The exact supported-part catalog is isolated in `accessport_catalog`. It is
assembled from vendor-published product identifiers and contains 64 part
numbers across 12 protocol families; see
[`ACCESSPORT_CATALOG.md`](ACCESSPORT_CATALOG.md). USB eligibility, authoritative
device identity, reviewed part support, and feature capability remain separate
decisions:

1. `accessport_usb` validates the USB descriptors and reads the device's
   authoritative identity.
2. `accessport_catalog` matches the returned part number exactly.
3. The identity response remains authoritative for the installed vehicle;
   RevLink never guesses a vehicle from the catalog's broad compatibility
   list.
4. Read-only file work proceeds only for an exact reviewed part.
5. An unknown part remains visible for troubleshooting but fails closed before
   namespace selection, listing, or downloading.

The portal publishes the catalog revision, family, and read-only file-sync
capability for both the attached device and selected cached dataset. Catalog
membership does not grant live telemetry, map decoding, firmware work, upload,
or deletion. See [`SUPPORTED_ACCESSPORTS.md`](SUPPORTED_ACCESSPORTS.md).

## Firmware slots and recovery

The 16 MiB P4 flash is divided into an immutable 4 MiB factory recovery image,
two 4 MiB OTA slots, redundant OTA selection data, NVS/PHY state, and a bounded
crash partition. ESP-IDF rollback support is compiled into the bootloader, but
no network update route exists yet. A future update service must write only the
inactive OTA slot and mark a pending image valid only after the bounded product
health gate passes. The partition contract and security gates are documented
in [`FIRMWARE_UPDATE.md`](FIRMWARE_UPDATE.md).

## Peripheral ownership and build profiles

The Waveshare development board exposes one P4 SD/MMC host to both its
onboard ESP32-C6 link and its microSD wiring. Resource ownership is therefore
selected at build time:

```text
default:
    SD/MMC -> microSD (4-bit)
    C6 radio -> disabled

wifi-scan:
    SD/MMC -> ESP32-C6 (4-bit SDIO)
    SPI3   -> microSD
```

The display remains on SPI2 and AccessPort traffic remains on the independent
high-speed USB host in both profiles. The storage port above FAT and the sync
coordinator do not know whether the card uses SDMMC or SPI; switching the
board adapter cannot change namespaces, manifests, immutable-object rules, or
transaction limits.

Managed-component presence is not authority to start hardware. The default
configuration explicitly disables `ESP_WIFI_REMOTE` and `ESP_HOSTED`, and the
radio source compiles its ESP-IDF Wi-Fi path only when the bounded profile is
selected. Both radio-off and radio-on images must build in CI. This prevents a
dependency update from silently claiming the SD/MMC controller.

The radio adapter supports an explicitly requested anonymous station scan, one
station connection, and one RAM-only WPA2 fallback SoftAP. It owns the ESP-IDF
station/AP netifs, hosted-radio mode changes, association events, AP client
count, and generated device SSID. It starts no HTTP server and persists no
credential itself. The independent `revlink_wifi_store` adapter owns the one
preferred station record; the network runtime saves it only after association
succeeds and loads it before the coordinator starts.

The platform-neutral `revlink_network` coordinator owns the product policy
above that adapter. It selects actions for saved-network scanning, one opaque
preferred-network connection, bounded same-network reconnect, and fallback
hotspot startup. While client-ready it schedules bounded local-link probes,
filters transient failures, and requests radio recovery after three
consecutive failures. It never handles an SSID, password, netif, ICMP packet,
or BLE packet.
Automatic background migration is intentionally absent, so a successful
lower-priority connection remains sticky until it is lost. HTTP, BLE, and
physical recovery controls will emit coordinator events rather than switching
the radio directly.

`revlink_network_runtime` is the P4 acceptance composition adapter between
those two layers. It converts coordinator actions into radio calls, hashes a
station identity into an opaque policy ID, ticks bounded timeouts, and reports
radio loss upward. It probes only the DHCP gateway, pauses probes during file
transfers, restarts the hosted radio on sustained failure, and applies a
one-reboot guard if both station and hotspot recovery are exhausted. It owns
only acceptance-time RAM credentials.
`revlink_credentials` centralizes their bounds and zeroization, while
`revlink_onboarding` translates bounded local HTTP requests into the same
runtime operation. Its captive DNS parser remains platform-neutral and does
not own sockets. The future encrypted credential repository remains a
separate port because selecting flash encryption or HMAC/eFuse provisioning
is an irreversible product-security decision. Sync terminal and start events
drive the coordinator's transfer lock so user-requested network mode changes
cannot interrupt an active file operation. The composition root asserts that
lock as soon as sync state becomes `queued`, keeps it asserted through
`running` and `cancelling`, and clears it only on a terminal state. The P4
runtime setter is idempotent so progress callbacks cannot generate redundant
policy events. Live acceptance rejected a mode transition submitted
immediately after queueing while allowing the read-only sync and acknowledged
AccessPort close to finish normally.

## Local control boundary

HTTP, BLE, a future display, and test tooling must not call USB or storage
adapters directly. They translate their input into the same platform-neutral
`revlink_control_request_t` command and receive a
`revlink_control_response_t` containing the current device, sync, policy, and
capability snapshot.

The accepted commands are status, saved auto-sync policy, manual sync, and
cooperative cancellation. Unknown commands fail closed. Mutating commands
also return the resulting snapshot so a UI does not need to guess whether its
request took effect. The ESP32-P4 composition root maps these commands onto
the runtime application. The portal's HTTP/JSON adapter, which ships, owns
serialization, request-size limits, and task serialization on top of it.

The optional development UART is the first concrete input adapter for this
boundary. `revlink_cli` accepts only `status`, `sync`, `cancel`, `auto on`,
`auto off`, and `help`; it cannot accept a path, protocol opcode, write, or
delete request. The P4 adapter incrementally reads printable characters from
the programming UART and never blocks the USB or display tasks waiting for a
line. This interface is bench tooling, not a product authentication boundary.

Output-only status surfaces subscribe to immutable lifecycle and sync
snapshots. `revlink_status` converts those snapshots into a small semantic
view—headline, detail, footer, severity, and progress—without knowing which
screen renders it. A monochrome OLED, future color display, LEDs, and an HTTP
status stream can therefore share product behavior without sharing a display
driver. Active sync/cancellation and reconnect safety messages have the
highest priority. After those states, current physical device absence or USB
fault takes priority over a prior terminal sync result so the display cannot
claim a completed backup indefinitely after the AccessPort is removed.

## Idle vehicle behavior and USB isolation

Controlled ESP32-P4 tests on 2026-07-26 proved that USB VBUS, high-speed
enumeration, and a complete descriptor scan do not by themselves put the
AccessPort into PC mode; Gauges remain available. ESP-IDF can then disable the
logical root port and report a clean host disconnect. This descriptor-only
result repeated after a clean P4 reboot.

Follow-up tests on 2026-07-26/27 proved that the session state preceding the
disconnect request is significant. A cold combined lifecycle test that never
established identity left the AccessPort on `connected to your computer`
after interface release and logical root-port shutdown. An isolated test that
sent only the capture-verified mini subtype `0x05` also produced no
subtype `0x35` acknowledgment, software re-enumeration, or return to Gauges.

A complete read-only session passed software-only exit acceptance on
2026-07-27. The P4 completed the identity handshake, listed and reconciled 33
datalogs against the per-device microSD manifest, sent subtype `0x05`, received
the expected subtype `0x35` acknowledgment, and released interface `0` with
`ESP_OK`. The AccessPort performed a software detach/re-enumeration and visibly
returned to Gauges while D+/D- and VBUS remained connected. The P4 classified
the new attachment as a polite software re-enumeration and did not start a
second transaction. The same scheduler subsequently accepted a combined
33-datalog/one-map inventory without changing this lifecycle.

The same lifecycle then passed five consecutive automated cycles. Every cycle
reconciled the same 33-file namespace, produced an acknowledged `0x05`/`0x35`
close, released interface `0` with `ESP_OK`, observed removal, and accepted a
fresh high-speed address before scheduling the next cycle. No cable action,
manual D+/D- switch, logical root-port shutdown, bus reset, or VBUS removal
was used.

Therefore the normal exit path is a polite subtype `0x05` close after a
successfully initialized session, followed by interface release. Logical
root-port shutdown and an unacknowledged or context-free subtype `0x05` remain
insufficient.

Do not automatically issue `SET_CONFIGURATION(0)` or a host-side bus reset
after the acknowledged close. Research proposed those as workarounds for a
missed soft disconnect, but the live P4 trace disproved that premise: ESP-IDF
reported the removal and re-enumeration on every accepted cycle. Preserve the
device-originated removal as lifecycle evidence instead.

A stale read-only PC-mode session was subsequently recovered by rebooting and
reinitializing the P4 host, completing the full bounded handshake, sending
subtype `0x05`, receiving subtype `0x35`, and releasing the interface. The
AccessPort returned to Gauges without opening D+/D- or removing VBUS.

The same recovery was then accepted under deterministic fault injection
without rebooting. Firmware deliberately omitted the first close after a
completed 33-file read-only reconciliation. The application queued one
dedicated recovery (never a second data sync), deferred it until the original
USB work item released the device, attempted the normal initialized identity
probe, and then issued the bounded close. Although the probe timed out against
the stale session, `0x05` received `0x35`; interface release succeeded, and
the AccessPort removed and re-enumerated at a fresh high-speed address.
Recovery success is therefore `acknowledged close + clean release`, while the
original sync retains its independent `data phase complete` evidence.

The retry budget is one per explicit or attachment-triggered sync. It is
eligible only when the original read-only data phase completed but its close
was not acknowledged. Data-phase failures, cancellation, write paths, and a
failed recovery do not recurse.

Software recovery is consequently the required primary path. A
GPIO-controlled reverse-blocking VBUS switch and high-speed data-path switch
with a true disabled state remain optional final-product defense in depth,
pending interrupted-transfer, timeout, repeated-cycle, crash, and write-fault
testing. Do not add unconditional VBUS discharge: an OBD-powered AccessPort
can hold the downstream node at 5 V and RevLink must not sink that external
supply.

### Safe shutdown boundary

The demo firmware reuses GPIO35/`BOOT` after boot as an active-low physical
control. The platform-neutral `revlink_power` component owns debounce and
reports short-release or long-hold intent. The P4 adapter maps a double press
to a context-aware network shortcut: the bounded, volatile Wi-Fi QR in local
hotspot mode, or the bounded `.local` browser address in preferred-network
mode. A single press dismisses either overlay. The URL overlay is unavailable
during active transfer work and is dismissed if sync begins or the preferred
network drops. A two-second hold maps to soft power. The P4 adapter owns the
shutdown side effects:

```text
block new syncs
    -> disable in-memory auto-sync
    -> cooperatively cancel active work
    -> wait for a terminal sync state
    -> isolate the board USB link as far as hardware permits
    -> abort incomplete storage work and unmount microSD
    -> deep sleep
```

If cancellation does not become quiescent within 30 seconds or the card
cannot unmount, firmware remains awake rather than risking an interrupted
transaction. The current Waveshare link adapter advertises no physical data
or VBUS isolation and performs logical root-port shutdown only. A custom-board
adapter may implement physical isolation without changing the power-button,
sync, or storage components.

The read-only file pipeline itself is now proven end to end. On 2026-07-26,
the ESP32-P4 issued one bounded `datalog` listing request, parsed 33 entries,
selected `datalog35.csv`, and streamed one download through the incremental
archive decoder into the atomic microSD cache sink. The sink published only
after exact-size and SHA-256 validation:

```text
46568 bytes
bff4f73f8aef276d354c8277bdc6547433f6f15a164ba41ebe2df1ff736e2688
```

This matches the Linux acceptance baseline byte for byte. An identical
existing cache entry was deduplicated. No retry, upload, delete, live-data,
reset, or disconnect transaction was sent. This validates the replaceable
protocol-decoder, USB-source, and storage-sink boundaries, but it does not
remove the separate requirement for drive-idle electrical isolation.

The next read-only gate promoted that path to bounded incremental sync. A
platform-neutral manifest component now owns file identity and serialization;
the ESP32-P4 SDMMC adapter owns durable publication and cache verification;
and the USB adapter owns one-session scheduling limits. The manifest records
device path, raw device timestamp, size, SHA-256, local cache name, and the
trusted UTC time when that exact version was first synchronized. A candidate
is skipped only after both metadata and the actual cached file verify.
Manifest v2 preserves that first-sync value across reconnects. Parsing remains
backward compatible with manifest v1; migrated entries use zero rather than
inventing a date.

The `revlink_time` component owns the replaceable UTC anchor. The P4
composition may initialize it from network time, a plausible retained RTC, or
the local browser clock when no stronger source exists. HTTP does not write
manifest fields directly: it submits a bounded time observation through the
time-service adapter. When UTC first becomes available, the storage adapter
repairs only zero-valued Initial sync fields for the last unambiguous device
namespace. Nonzero values remain immutable. A supported rechargeable RTC
battery is still required to retain accurate time through a complete
unattended power loss.

Editable user annotations are deliberately stored outside both authoritative
sync documents. `revlink_sync_annotations` keys each note by the cached
content's SHA-256 inside that AccessPort's namespace. A note therefore follows
identical bytes across a rename, does not leak to replacement content when a
native filename rotates, and cannot make a valid sync manifest unreadable.
Notes support multiline UTF-8 text up to 767 bytes. Their update time is zero
while wall-clock time is untrusted and UTC only after the time service has a
trusted source. The platform adapter must publish changes using the same
temporary-file, `fsync`, backup, and atomic-rename pattern as manifests.

The FAT adapter uses `current`, `.tmp`, and `.bak` manifest files because FAT
rename cannot atomically replace an existing destination. Data publication
still precedes manifest advancement, so an interruption can leave a safe
unindexed file but cannot create a manifest entry for incomplete data. On the
physical board, an interrupted run resumed from one valid entry, deduplicated
the already completed next file, and advanced to five entries. A reset then
loaded those five entries, verified and skipped all five, and downloaded the
next four. The two accepted bounded sessions reported `4 downloaded / 1
skipped` and `4 downloaded / 5 skipped`, respectively, and both released the
interface cleanly with writes disabled.

### Multi-device identity and immutable file history

Persistent data is never keyed by the USB descriptor serial. The connected
AccessPort exposes the placeholder
`0123456789.0123456789.0123456789`; the file session therefore sends the four
capture-verified read-only identity mini requests and parses the third
`0x1601` response before storage can be selected. A sync fails closed if the
true serial cannot be obtained or if a namespace's stored identity disagrees.

The storage key is the first 24 lowercase hexadecimal characters of
`SHA-256("revlink-device-v1:" + true_serial)`. Every AccessPort owns a
completely separate directory:

```text
/revlink/devices/<device-key>/
  identity.txt
  annotations.tsv
  current/inventory.manifest
  history/inventory.versions
  objects/datalogs/<full-sha256>.csv[.gz]
  objects/maps/<full-sha256>.ptm
  tmp/
```

The `current` manifest answers “what bytes are currently observed at this
remote path?” while the append-only version journal answers “what bytes have
ever been observed at this path?” Object names are content-addressed by the
full SHA-256, so AccessPort filename rotation cannot overwrite an older log
or map. The remote path—including its `datalog/` or `maps/` collection—is the
authoritative manifest key. Equal filenames in different collections cannot
collide.

### Diagnostic map context

A diagnostic case may optionally reference the map used while its evidence
logs were recorded. The reference is an immutable snapshot containing the
device-scoped map path, full content SHA-256, byte size, initial-sync time, and
available device timestamp metadata. A filename alone is never sufficient:
AccessPort files can be replaced under the same name, and a later replacement
must not silently change an existing case.

The future tuning-summary engine attaches its own versioned result to this
snapshot. It may describe a change only when both the selected map and an
explicit baseline are available through a parser with verified provenance.
Opaque PTM bytes, a filename such as `stage2`, or tuner-supplied timestamps
must not be converted into guessed table or calibration changes. Until those
requirements are met, the UI shows the verified map identity without claiming
a tuning summary.

The commit order is object, version history, then current manifest. A power
loss may leave a safe orphan object or an already-recorded history entry, but
cannot make incomplete bytes current. Both journals use the FAT-safe
`current`/`.tmp`/`.bak` publication pattern and recover an interrupted
publish.

The portal's offline projection is also independent of the Sidecar network
identity. `/revlink/last-device` is a small versioned, FAT-safe pointer to the
last AccessPort namespace selected by an authoritative identity handshake.
At boot, the adapter verifies that namespace's `identity.txt`, re-derives its
key from the stored true serial, then loads the current manifest and notes for
read-only portal display. It immediately releases session selection, so a
later USB operation cannot inherit writable state from the cached projection.

For cards created before this pointer existed, the migration selects a device
only when exactly one valid namespace is present. Multiple namespaces without
a pointer are intentionally ambiguous: the portal waits for a real sync
instead of merging data or guessing which device is current. Changing the
Sidecar hostname, SSID, collision suffix, or internal `r1_...` ID therefore
cannot orphan or re-key AccessPort data.

When one eligible AccessPort is attached, the runtime automatically queues an
identity-only work item after enumeration unless a full auto-sync is already
queued or running. It executes the same four capture-verified read-only
identity mini requests and acknowledged `0x05`/`0x35` close as a full sync,
but does not list or download files. This establishes
`attachedAccessPort` immediately and creates/selects the correct empty
namespace for a previously unseen unit. A polite software re-enumeration
preserves that live identity; a genuine physical detach clears it. The user
may subsequently select a different cached namespace for browsing without
changing the attached identity.

The unified ledger names supersede the original datalog-specific filenames.
On upgrade, the storage adapter atomically adopts the legacy primary manifest
and history files only when their unified destinations do not exist. Live
acceptance after reset loaded all 34 pre-upgrade entries, SHA-verified and
skipped all 33 datalogs plus one map, transferred zero bytes, and left writes
disabled.

This architecture was accepted live on the ESP32-P4 on 2026-07-26. The board
read true serial `SUB0406661`, selected device key
`d2313ecdf618801b8d5b1270`, SHA-verified four existing immutable objects, and
downloaded four more. After reset it loaded eight current/history entries,
verified and skipped all eight, and downloaded the next four. The sessions
reported `4 downloaded / 4 skipped` and `4 downloaded / 8 skipped`; both
released interface 0 with `ESP_OK`, and all write/delete capabilities remained
disabled. The board was then restored to its normal descriptor-only firmware.

### Attachment-scoped session lifecycle

Sync eligibility belongs to an enumerated physical attachment, not to the
firmware boot. A newly accepted USB device record may run one bounded session.
When that session ends, the USB adapter releases interface `0` and tells the
storage adapter to abort any active writer, clear its in-memory manifests and
history, and forget the selected device namespace. A detach destroys the USB
record. A subsequent attach therefore re-reads authoritative identity and may
run another bounded session without rebooting.

This prevents three classes of cross-session error:

- a reconnect cannot be blocked by a boot-global “already synced” flag;
- a replacement AccessPort cannot inherit another device's manifest; and
- a failed or unplugged transfer cannot leave a writable temporary object
  selected for the next session.

The same-device reconnect path passed live on 2026-07-26. The first attachment
loaded 16 entries, downloaded four, and released at 20. After physical
unplug/replug, the unchanged firmware accepted the new USB address, re-read
serial `SUB0406661`, verified and skipped all 20 current objects, downloaded
four more, and released at 24. Both sessions closed with `ESP_OK`; writes and
deletes remained disabled. A host lifecycle test repeats the detach/attach
flow with a different identity to cover device replacement.

### Normal runtime sync coordinator

The accepted file pipeline is now part of the normal application flow rather
than a boot-global acceptance shortcut. `revlink_sync_coordinator` owns the
platform-neutral state machine:

```text
idle -> queued -> running -> completed
                  |   |
                  |   `-> failed
                  `-> cancelling -> cancelled
```

The application requests work through a transport port and receives immutable
progress events back from the USB adapter. Its snapshot contains the current
state, candidates, verified skips, downloads, downloaded bytes, pending files,
and the last platform error. A manual request is accepted only while the
device lifecycle is `available`. Auto-sync runs at most once for a newly
accepted physical attachment; returning from `session-active` to `available`
does not create a loop. A detach resets attachment eligibility.

Auto-sync policy is persisted by the ESP32-P4 composition root in NVS under
namespace `revlink`, key `auto_sync`. It defaults off. NVS stores only this
preference—device manifests and log history remain on microSD. The public
composition-root API is:

```c
revlink_runtime_set_auto_sync(bool enabled);
revlink_runtime_request_sync(void);
revlink_runtime_cancel_sync(void);
revlink_runtime_sync_policy(void);
revlink_runtime_sync_snapshot(void);
```

Cancellation is cooperative and lock-free: the USB owner task accepts the
cancel request through its control queue and publishes an atomic cancellation
flag. The descriptor worker checks it between identity transactions, archive
reads, listing reads, candidates, and download payload reads. It never tears
down a transfer buffer or USB handle from another task. Completion, failure,
cancel, and physical detach all abort any temporary writer, release interface
`0`, and release the selected device namespace.

The normal coordinator path passed live on the ESP32-P4 on 2026-07-26 using a
test-only auto-sync default. It selected true serial `SUB0406661`, loaded 24
current entries, verified and skipped all 24 immutable objects, downloaded
four new objects, and reported:

```text
candidates=33 downloaded=4 skipped=24 bytes=8008571 pending=5
```

The session released interface `0` with `ESP_OK`, returned the device to
`available`, and released namespace `d2313ecdf618801b8d5b1270`. The board was
then restored to the production build and boot-verified with runtime sync
enabled, auto-sync off, every legacy acceptance gate off, and device writes
disabled. The test-only overlay is
`firmware/esp32p4/sdkconfig.runtime-sync.defaults`.

The consumer hardware must therefore expose USB link control as a replaceable
platform adapter. The application-level behavior is:

```text
drive idle
    -> AccessPort powered by vehicle
    -> RevLink VBUS off and data path isolated
    -> on-device Gauges remain available

sync requested
    -> enable protected VBUS/data path
    -> enumerate and open a bounded file session
    -> perform the requested operation
    -> send the polite session-end transaction when applicable
    -> cancel work, release the interface, and stop the host port
    -> isolate data and remove RevLink-supplied VBUS
    -> return to drive idle
```

If a controllable USB power stage is retained, it must prevent backfeeding
when the AccessPort is already powered from its OBD cable. It needs
GPIO-controlled enable, current limiting, fault reporting, controlled
turn-off without an unconditional downstream discharge path, and
reverse-current protection. If a high-speed data switch is retained, it needs
a USB 2.0 high-speed-rated disabled/high-impedance state. These optional
controls are distinct from protocol Connect/Disconnect and from ESP-IDF's
logical root-port state.

The current Waveshare ESP32-P4 development board cannot provide a true
electrical detach by firmware alone. Its USB-A `VBUS_OUT` switch enable
is hardware-pulled on, and its high-speed data route is selected by the
physical OTG jumper rather than a GPIO. A controlled external power/data stage
is no longer required for current prototype acceptance. The ordered TS3USB221
module remains a useful optional test article; its results and the remaining
failure-injection matrix will determine whether physical data isolation
belongs on the production PCB.

### Platform-neutral USB electrical control

`firmware/components/revlink_usb_control` owns the portable electrical-link
state machine. Host tests cover fail-safe initialization, RevLink-supplied
VBUS attach, externally powered data-only attach, data-before-power isolation,
invalid transitions, forced isolation after a driver error, and idempotent
disconnect.

Platform adapters own GPIO numbers, active polarities, delays, and future
fault/sense inputs. The portable component deliberately contains none of
those board details. GPIO39 through GPIO44 are already reserved by the
accepted four-bit microSD interface, so temporary USB-control pins remain
unassigned until the complete development-board pin and boot-strap audit is
finished.

## Vehicle power lifecycle

Use a switched vehicle USB source as the preferred ACC/RUN proxy. A protected
charger and power-path controller must keep RevLink running from its battery
after external USB disappears and expose a 3.3 V-safe power-good signal to an
ESP32-P4 low-power wake GPIO.

External-power loss starts a grace timer rather than cutting the system off.
After active work is complete, firmware flushes storage, stops USB and radio
services, and enters deep sleep. External-power return cancels the timer or
wakes the P4. See [`POWER_MANAGEMENT.md`](POWER_MANAGEMENT.md) for the
deterministic state model and acceptance checks.

If electrical isolation is retained as final-product defense in depth, test
these cases independently:

1. AccessPort on OBD power with RevLink idle: Gauges remain available.
2. RevLink initiates sync: the AccessPort enumerates at high speed.
3. Sync completes: the acknowledged software close returns Gauges before any
   optional hardware isolation is exercised.
4. RevLink reboots or crashes: hardware defaults to the isolated state.
5. OBD and RevLink power overlap: neither supply backfeeds the other.
6. Cable attach detection does not require leaving the AccessPort in PC mode.

## Concurrency and ownership rules

- One component owns each peripheral handle and its worker tasks.
- Callers exchange immutable events, bounded requests, or owned buffers.
- No browser or HTTP handler talks directly to USB.
- The local portal issues transport-neutral `revlink_control` requests and
  reads an immutable storage projection. The SD adapter publishes at most 128
  current-manifest entries, labels each projection as `datalog` or `map`, and
  preserves the last authoritative device namespace after the file session
  closes.
- Portal responses use bounded bodies and close their HTTP connection.
  The P4 composition reserves a 16-socket LWIP pool so the HTTP server,
  captive DNS, mDNS, and network coordinator cannot exhaust one another under
  normal dashboard polling. The 2026-07-27 live pass completed 80
  concurrent/repeated status requests without an accept failure.
- Device transactions are serialized by the USB adapter's bounded work and
  control queues; future transports must preserve this single-session rule.
- Every asynchronous sync request has bounded transfers, progress events, and
  a cooperative cancellation path.
- Disconnect cancels outstanding work before handles or buffers are released.
- Large files are streamed through bounded buffers; they are not loaded whole
  into RAM.
- Persistent writes use temporary files, flush, checksum verification, and
  atomic rename.
- A component reports errors upward; it does not restart unrelated systems.

## Adding or replacing a subsystem

1. Define or extend a platform-neutral port under `revlink_core` or the
   application layer.
2. Write host tests for behavior and failure transitions.
3. Implement the platform adapter in its own component.
4. Select the adapter only in the board composition root.
5. Add a hardware acceptance gate that is disabled by default.
6. Preserve the previous adapter until parity and recovery behavior pass.

For example, replacing microSD with eMMC should require a new storage adapter,
not changes to device sync, the HTTP API, or AccessPort protocol framing.

## Test gates

Host tests must pass before a board build:

```sh
source "$HOME/.espressif/frameworks/esp-idf-v6.0.2/export.sh"
cmake -S firmware/test -B firmware/test/build
cmake --build firmware/test/build --parallel
ctest --test-dir firmware/test/build --output-on-failure
```

These cover protocol vectors, lifecycle transitions, strict root-list response
parsing, incremental fragmented download decoding, both capture-valid JAMCRC
and device-observed zero trailers, corrupt-trailer rejection, sink-failure
propagation, and default-deny write/delete policy. The captured-request parity
suite is not part of this repository — it replays a corpus of USB captures that
is not published here — so `protocol_unit` covers the builders and parsers
against self-contained vectors instead.

Then build the shipped Nano profile. Fragment order matters: the list must end
with `sdkconfig.nano.defaults`, because `sdkconfig.oled.defaults` carries
`# CONFIG_REVLINK_ALLOW_DEVICE_WRITES is not set` and would otherwise be the
last word on it, producing a writes-off image.

```sh
NANO_BUILD="$PWD/firmware/esp32p4/build-nano"
idf.py -C firmware/esp32p4 \
  -B "$NANO_BUILD" \
  -D "SDKCONFIG=$NANO_BUILD/sdkconfig" \
  -D 'SDKCONFIG_DEFAULTS=sdkconfig.defaults;sdkconfig.oled.defaults;sdkconfig.wifi-scan.defaults;sdkconfig.wifi-join.defaults;sdkconfig.network-runtime.defaults;sdkconfig.onboarding.defaults;sdkconfig.nano.defaults' \
  set-target esp32p4 build
```

Hardware acceptance remains staged. Enabling an interface, read, write,
delete, format, or recovery gate is a deliberate test decision; successful
compilation never grants that authority.

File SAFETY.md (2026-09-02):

# Safety model

This project talks to a device that holds the maps your car runs on. The
constraints below are not stylistic — they are the reason this is safe to
plug into a vehicle. Please do not relax them casually in a pull request.

## The one-sentence version

Reading is safe and enabled. Writing works and has been done against real
hardware, but it is off by default, requires two independent unlocks, is
restricted to two exact destinations, and refuses to proceed the moment
anything is ambiguous. What is genuinely new is RevLink starting a write
without being asked; see automatic application below.

## Read vs. write

| Operation | Status | Notes |
| --- | --- | --- |
| List directories | Enabled | Read-only |
| Download files | Enabled | Verified by size and SHA-256, published atomically |
| Upload a map file | **Gated** | Compile flag + persistent owner consent. Copies a `.ptm` onto the AccessPort's storage; it does not install anything onto an ECU |
| Auto-apply a staged map | **Gated** | The above, plus a separate preference and a matching pinned device — see [STAGED_MAPS.md](docs/STAGED_MAPS.md) |
| Replace the startup screen | **Gated** | Fixed destination only |
| Delete a file from the AccessPort | **Gated** | `maps/` and `datalog/` only, one level deep. Its own compile flag and its own consent, neither implied by the write gates |
| Remove the Sidecar's cached copy | Confirmed per action | The owner's own microSD. No device involved, so no AccessPort consent — but it is the one action that can leave a file nowhere, so the portal says so and offers the download first |
| ECU flashing / live tuning | **Out of scope permanently** | Not a goal of this project |

## What a "write" is here

A write copies a file onto the AccessPort's own storage. It does not put a
calibration into a vehicle. Installing a map onto the ECU is a separate,
deliberate action the owner takes on the AccessPort itself, and nothing in
this project can perform it or trigger it.

That is why the published image ships with writes compiled in: the failure
this project can plausibly cause is a damaged file or a confused `maps/`
directory on the AccessPort, not a damaged engine.

It stays gated anyway, and the reason is not doubt about the code. The write
path has been accepted on hardware and is in regular use; the gate is there
because writing to someone's device is their decision to make, not a default
to be assumed. Consent starts locked on a new or factory-reset Sidecar and
persists in NVS until the owner changes it — it does not re-lock on reboot.

## Deletion is gated separately

Deletion has its own compile flag (`CONFIG_REVLINK_ALLOW_DEVICE_DELETES`,
default `n`) and its own runtime consent. Neither is implied by the write
gates.

That separation is the point. Agreeing to copy maps onto a device is not
agreeing to let this remove files from it, and a shared flag would convert one
decision into the other. Deletion also has no undo: the AccessPort keeps no
recycle bin, and the Sidecar holds nothing back beyond whatever it had already
synchronised.

Only a file directly inside `maps/` or `datalog/` can be removed — not
`images/`, not the directories themselves, nothing nested, no traversal. Every
delete pins the device by part number and serial, requires the file to be
present first, and re-lists the directory afterwards to confirm it is gone. A
delete is never transmitted for a file the device does not list. Each one is
appended to an audit log on the card.

From 0.2.2 the published image contains it. Compiling it in is not enabling
it: delete consent is a separate runtime switch, locked until the owner sets
it and never implied by agreeing to map transfers. Like write consent it is
stored in NVS, so once granted it stays granted until it is turned off. The reason to ship it is the same reason writes ship — without a
computer, a full AccessPort cannot be cleared, and that is one of the two
problems this project exists to solve. What deletion can cost you is a file
you meant to keep. The Sidecar's own synced copy survives a device delete —
unless you separately choose to remove that too, which is the one action in
the product that can leave a file nowhere.

## The two write gates

A map write requires **both**:

1. `CONFIG_REVLINK_ALLOW_DEVICE_WRITES` compiled into the image. Without it,
   the write service returns `ESP_ERR_NOT_SUPPORTED` and no write code path
   exists at runtime.
2. **Persistent owner consent** enabled in portal Settings. New and
   factory-reset Sidecars default to locked.

Neither gate implies the other. Compiling writes in does not enable them.

## Destination allow-list

The generic protocol serializer can express more than the product permits.
That is deliberate — it lets the serializer be checked against every captured
request. The *product policy* is narrower and authorizes exactly:

- `maps/<name>.ptm` — one directory level, no traversal, no subdirectories
- `images/startup_screen.fb` — the exact startup framebuffer, fixed size

Everything else is refused, including captured CSV upload paths.

## Fail closed, never guess

- **Two attached AccessPorts produce a first-class conflict state**, not an
  arbitrary selection. See
  [`docs/SINGLE_ACCESSPORT_SAFETY.md`](docs/SINGLE_ACCESSPORT_SAFETY.md).
- **Stale USB topology events are rejected** by a transport-owned monotonic
  revision, so a late detach cannot invalidate a newer attach.
- **Device operations are serialized.** No concurrent transactions.
- **Checksum mismatches are hard failures.** Never a warning.
- **Writes are never retried automatically.** A failed write stops and
  requires a deliberate human action.
- **Downloads publish atomically** — temp file, flush, checksum, rename — so
  power loss cannot turn a partial download into a valid cache entry.

## Network posture

The portal has **no transport encryption**. It is designed for a trusted local
network: your own Wi-Fi, or the Sidecar's own fallback hotspot.

Do not port-forward it. Do not expose it to the public internet. If you want
remote access, put it behind a VPN or a private overlay network.

## What has actually been proven on hardware

Claims here are limited to what has been verified on a real device.

**Accepted:**

- USB enumeration of the AccessPort at high speed with correct endpoints
- Root, `datalog/`, and `maps/` listings, repeatedly
- Incremental download with exact size and SHA-256 match against a known
  baseline, published atomically to microSD
- Byte-exact protocol reconstruction of the full captured request corpus
- Wi-Fi client rejoin, fallback hotspot, and captive portal across cold boots
- Two-second BOOT-button safe shutdown with an idle attached AccessPort
- The BOOT double-press network shortcut. A standard `WIFI:T:WPA;S:…;P:…;`
  join code is generated on the device and rendered on the SH1106, scanned
  from a phone to join the Sidecar's hotspot. The panel is 128x64 and a
  version-3 symbol is 29 modules, so it renders at 2x with almost nothing to
  spare — that it scans reliably off a screen that small was the open question,
  and it does
- A complete logical backup export downloaded end to end, 128 files, with the
  device staying up throughout
- A map staged with no AccessPort attached, surviving a power cycle: restored
  at boot with its recorded size and SHA-256 re-verified, and still pinned to
  the part number it was saved for
- A staged map applied automatically, with nobody pressing anything: written
  after a clean sync to the AccessPort it was pinned to, and verified by
  read-back (`MAP WRITE VERIFIED ... ready/completion/readback=passed`)
- Deleting a file from an AccessPort: refused while consent was locked, refused
  for every path outside the allowlist, then removed and confirmed absent by
  re-listing (`FILE DELETED ... confirmed_absent=yes`). A second attempt at the
  same path was refused without transmitting anything
- Removing the Sidecar's own cached copy, and removing a file from both places
  in one action — the case that leaves no copy anywhere. Accepted on 0.2.5,
  after two releases in which the button was drawn, the request was sent, and
  the firmware refused it with no visible symptom beyond the file staying
  where it was
- Writing maps to an AccessPort, repeatedly and in ordinary use — not a single
  lab pass. The maintainer has transferred several different maps to a device
  in service, each read back and matched by SHA-256 before being reported as
  done, and the files survive power cycles and are usable from the AccessPort
  afterwards. The first live pass reported a misleading `ESP_ERR_INVALID_CRC`
  because the local cache's path validator rejected spaces in map names; the
  transfer itself had already completed. Validators now accept safe spaces and
  parentheses, with host tests covering those names.
  See docs/MAP_WRITE_ACCEPTANCE.md

**Not yet accepted on hardware:**

- The scripted round-trip in docs/MAP_WRITE_ACCEPTANCE.md as one recorded
  ceremony. Every step in it has been done — writing, read-back verification,
  listing, deletion — but on separate occasions rather than as one transcript
- Startup-screen replacement against a device
- Powered-hub behavior with two AccessPorts attached
- A second AccessPort arriving *during* a write or delete. Between
  transactions the transport already refuses unless exactly one eligible
  device is present, but the mid-operation path has not been exercised —
  see docs/SINGLE_ACCESSPORT_SAFETY.md
- Cooperative cancellation and shutdown *during* an active sync
- Restoring a logical backup onto a card. The export side has run end to end;
  the merge has only ever been host-tested

Do not describe the unaccepted items as working, in documentation or in a
release. If you accept one on real hardware, move it up and say what you
verified.

## Reporting a security or safety issue

Please open an issue for ordinary bugs. For anything that could damage a
device or a vehicle, or that could cause a write to reach the wrong target,
please report it privately through GitHub's security advisory flow on this
repository rather than in a public issue.

## Logical backup export takes minutes

`GET /api/portal/backup` reads and checksums every cached file, then streams
them. On a card holding a few hundred megabytes of datalogs that is several
minutes — 128 files took about two and a half on the reference Nano.

The embedded HTTP server handles one request at a time, so nothing else is
served while that runs. Leave the tab open. The portal stops polling for the
duration and does not treat a timeout during a known-busy period as a lost
connection; before that it declared the Sidecar offline about fifteen seconds
in, while the backup was streaming perfectly well underneath.

Verified on hardware: a complete export downloads successfully, and the
device stays up through it. Heap holds flat at 33 MiB and the HTTP task keeps
about 6 KiB of stack spare for the whole run.

## Fixed in 0.2.2: restore path's 4 KiB stack buffers

`validate_pending()`, `skip_bytes()` and `revlink_backup_restore_merge()` each
held a `BACKUP_BUFFER_BYTES` array on the stack, on the same HTTP server task
whose export equivalents had to be moved to the heap. The worst case was
8 KiB, not 4: `restore_merge()` calls `skip_bytes()` from inside its loop with
its own buffer still live, against a 12 KiB stack that had itself been raised
from 6 KiB after a measured 6116-byte peak overflowed it.

Restore still has not been exercised on hardware, so this was never observed
to fail — it was the same arithmetic that had already overflowed once
elsewhere. The buffers are now on the heap, and `skip_bytes()` borrows its
caller's rather than allocating a second one.

The trap, recorded because it is easy to walk into again: those loops sized
their reads with `sizeof(buffer)`, which silently becomes the size of a
pointer the moment the array becomes a `malloc` — a four-byte read loop that
passes every test. They name the constant now, and the file has no
`sizeof(buffer)` left in it.

## The only action that can leave no copy

Every destructive operation here normally leaves a copy somewhere. Delete from
the AccessPort and the Sidecar still has it. Remove it from the Sidecar and the
AccessPort still has it. Removing both is the single exception, and the Sidecar
has no recycle bin any more than the AccessPort does.

So it is asked as its own question, after the first one, and never bundled into
a prompt about deleting from the device. The confirmation says the file will
not exist anywhere afterwards and offers to download it first. Declining
anywhere in the chain keeps the cached copy, because that is the outcome you
can still recover from.

Removing the cache alone deliberately does *not* require the AccessPort delete
consent. That switch exists to protect somebody's device; the microSD is the
owner's own storage, which they can already empty by removing the card.
Granting one permission on the strength of another is the thing the write and
delete gates are kept separate to avoid, and it would apply just as much here.

## Presence is three-valued, and absence needs evidence

The Sidecar keeps its own copy of everything it syncs, so a file can exist
here and not on the AccessPort. Since 0.2.2 each cached file records whether
the last *completed* listing found it on the device, and the portal says
"Sidecar only" for one that is gone.

The state is deliberately three-valued. A sync that was cancelled, failed, or
was cut short proves nothing about what is on the device, and a manifest
written by an earlier build carries no evidence at all; both read as unknown
rather than as absence. The API reports `null` for that case, and `null` is
not `false`. Telling an owner their files had been removed because a sync was
interrupted would be a worse failure than saying nothing.

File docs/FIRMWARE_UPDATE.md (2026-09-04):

# Firmware update and recovery architecture

RevLink Sidecar uses the ESP32-P4 development board's 16 MiB flash as a
firmware and recovery device. Datalogs, maps, images, manifests, and other
user-owned files remain on microSD.

## Partition contract

| Partition | Offset | Size | Purpose |
|---|---:|---:|---|
| `nvs` | `0x009000` | 24 KiB | Device policy and settings |
| `otadata` | `0x00f000` | 8 KiB | Redundant OTA boot selection |
| `phy_init` | `0x011000` | 4 KiB | Radio PHY initialization |
| `factory` | `0x020000` | 4 MiB | Stable recovery image |
| `ota_0` | `0x420000` | 4 MiB | Normal release slot A |
| `ota_1` | `0x820000` | 4 MiB | Normal release slot B |
| `coredump` | `0xc20000` | 64 KiB | Reserved bounded crash evidence |

The region from `0xc30000` through the end of flash remains unallocated. It is
reserved for the production security and credential design, including any
future encrypted-NVS keys or recovery metadata. It must not become general
application storage.

The coredump partition is reserved by the layout but flash coredumps are not
enabled yet. Before enabling them, define retention, local export, redaction,
and erase behavior so a crash record cannot become an accidental source of
credentials or user data.

## Release lifecycle

1. A factory-programmed board boots the stable `factory` image.
2. A verified update is written only to the inactive OTA slot.
3. The bootloader marks the new slot pending verification and boots it once.
4. The new image runs bounded health checks.
5. Only after the critical services are healthy does the application call
   `esp_ota_mark_app_valid_cancel_rollback()`.
6. A crash, watchdog reset, power loss, or reboot before confirmation causes
   the bootloader to return to the previous working image.

The update transport is not implemented yet. Until it is, firmware is flashed
locally through the development interface. Do not add a browser upload route
that writes arbitrary bytes directly to an application partition.

**The order these are built in is load-bearing.** Rollback is already armed —
`CONFIG_BOOTLOADER_APP_ROLLBACK_ENABLE=y` in `sdkconfig.defaults` — while step
5 has no implementation, so nothing in the tree calls
`esp_ota_mark_app_valid_cancel_rollback()`. That is harmless only because
published images flash to `factory`, which is not subject to pending
verification, and `ota_0`/`ota_1` are allocated but unused.

Ship a transport before the health gate and every update boots once and
reverts. The symptom is an update that appears to install and then silently
does not take, with the cause sitting in the bootloader's state machine rather
than in the transport that appears to be at fault. Build the gate first, or
with it. Tracked in #21.

## Required health gate

The platform-neutral decision layer is implemented in
`firmware/components/revlink_update/`. It tracks a bounded post-boot timeout,
reports the first blocking subsystem, accepts explicitly recoverable microSD
absence, treats the display as optional when it is not configured, and rejects
an unsafe/default-allow transfer policy immediately. Its terminal result is
sticky so a late service recovery cannot mark an already timed-out image
healthy.

This component does not select an OTA partition or mark an image valid. The
ESP-IDF adapter that supplies real subsystem observations and calls
`esp_ota_mark_app_valid_cancel_rollback()` remains unimplemented.

An OTA release must not be confirmed merely because `app_main()` started. The
health gate must prove, within a bounded timeout:

- NVS initialized without destructive recovery;
- the microSD repository mounted or reported a clear recoverable absence;
- the status display task is alive when the display is configured;
- the network coordinator reached a valid client, hotspot, or intentional
  offline state;
- the local portal can answer its internal health request;
- the USB runtime is waiting, available, or deliberately disabled rather than
  fault-looping; and
- the shared transfer/write safety policy remains default-deny.

The AccessPort does not need to be physically attached for an update to become
healthy.

The host suite covers delayed readiness, required and optional displays,
recoverable storage absence, timeout, elapsed-time saturation, invalid
observations, and immediate terminal rejection when the safety policy is not
default-deny.

## Recovery and factory reset

Rollback and factory reset are separate operations:

- **Rollback** automatically returns to the previously working OTA image.
- **Recovery** intentionally selects the immutable factory image.
- **Factory reset** may additionally erase selected settings and credentials.

No boot-time factory-reset GPIO is enabled on the development board. The final
gesture must be chosen only after the shutdown, eject, Wi-Fi recovery, and
factory-reset button map and GPIO allocation are approved. A reset must never
erase the microSD dataset silently.

## Security gates before remote updates

Before enabling network-delivered firmware:

- define signed release artifacts and version metadata;
- require cryptographic signature verification before selecting an image;
- use HTTPS or an authenticated local upload channel;
- reject downgrades according to a documented policy;
- preserve power-loss safety and inactive-slot-only writes;
- record the result without logging credentials;
- add a user-visible update and rollback state; and
- complete repeatable update, interruption, corruption, and rollback tests.

Secure Boot, flash encryption, anti-rollback eFuses, and encrypted NVS are
production provisioning decisions. Do not burn irreversible eFuses during
prototype acceptance.

## Prototype acceptance

The layout was flashed to the Waveshare ESP32-P4 board and boot-accepted on
2026-07-27. The bootloader selected the factory image at `0x20000`; the
1.07 MB image left 74% of each 4 MiB application slot free. The existing
63.8 GB microSD mounted without formatting, the fallback hotspot returned,
the high-speed USB host initialized, and the attached AccessPort reported
available. Auto-sync remained off and AccessPort writes remained locked.

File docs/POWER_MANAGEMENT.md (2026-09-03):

# RevLink power management

## Switched USB as the vehicle-on signal

The preferred prototype input is a USB source that is powered only while the
vehicle is in ACC or RUN, such as a switched radio or console USB output.
RevLink must not rely on that input as its only supply. A battery and
power-path controller keep the system alive when external USB disappears.

Use the power-path controller's USB-present or power-good output as the
firmware signal. If the selected controller does not expose one, add a
protected 5 V presence detector whose output is safe for a 3.3 V ESP32-P4
low-power GPIO. Never connect USB VBUS directly to a GPIO.

```text
switched vehicle USB
    -> protected charger and power-path controller
       -> system rail
       -> battery charging
       -> USB-present / power-good -> ESP32-P4 low-power wake GPIO
```

The controller must support simultaneous charging and system load, seamless
handoff to the battery, reverse-current protection, and enough peak current
for the P4, C6 radio, microSD, and AccessPort USB host path.

## Measured draw

Measured 2026-09-02 with an inline USB meter on the 5 V rail feeding the Nano's
USB-C port, with an AccessPort attached:

| Condition | Current | Voltage | Power |
| --- | --- | --- | --- |
| Steady, connected and syncing | 0.12 – 0.16 A | 4.86 V | 0.58 – 0.77 W |
| Cold boot, AccessPort attached, initial sync | 0.20 A | 4.85 V | 0.96 W |
| **Highest seen — cold boot after an unplug/replug** | **0.28 A** | **4.74 V** | **1.32 W** |

The 4.74 V in that last row is an artefact of the measurement path, not the
supply — see below.

After the initial sync it settles back to the steady range.

That is the whole system: ESP32-P4 with 32 MB PSRAM, the ESP32-C6 radio over
SDIO, microSD, and the AccessPort as a downstream USB device. It is far lower
than the figure this section was written in anticipation of, and it changes
what "enough peak current" has to mean — a 1 A supply has roughly six times the
headroom needed for steady-state operation.

0.28 A is only **28% of the TPS61023's 1 A ceiling**, and about 0.2C on a
2000 mAh cell, so current is not the constraint. Runtime is roughly 5 hours if
it somehow held at that peak and 8 or more in practice.

### The constraint is voltage, not current

Those four points make a load line, and it slopes:

```text
0.12 A -> 4.86 V
0.16 A -> 4.86 V
0.20 A -> 4.85 V
0.28 A -> 4.74 V
```

That is roughly **1.4 ohm** of effective series resistance between the boost
and the meter. USB VBUS is specified as 4.75 – 5.25 V, so at 0.28 A the rail is
already a hair under the floor, and extrapolating the same slope gives about
4.6 V at 0.35 A and 4.4 V at 0.5 A.

**It was the wiring, not the board.** 1.4 ohm was always too high to be the
boost converter's regulation. Feeding the 5 V rail directly at the header —
P2 pin 1 for 5 V and pin 3 for GND — removes the USB meter, a USB-C adapter,
the cable and two connectors from the path, and **the sag disappears**.

So the load line above measures a test rig, not the supply. Record it anyway,
because it is a useful reminder of how much a convenient measurement setup can
invent: a rail that looked marginal against the USB minimum was actually fine,
and the instrument was the problem.

Two things follow. Take bench readings **at the board**, not at an inline meter
several connectors upstream. And in a permanent install, feed the header
directly rather than through a USB-C lead, for the same reason it fixed the
measurement — every connector in the path costs voltage at exactly the moment
current peaks.

The AccessPort's VBUS derives from this same rail, so whatever the rail sags
to, the attached device sees less. That is why this mattered enough to chase.

### Cold boot from battery works

This was the open question, because a boost converter that cannot start into
the load makes the whole approach unusable. The Adafruit TPS61023 board is
documented as stalling on a load that draws full current immediately, above
roughly 200 mA.

The measured cold-boot peak is **exactly 200 mA**, and the Sidecar starts
anyway — the P4 evidently ramps as PSRAM and the radio come up rather than
slamming to full draw at the instant power appears, which is the case the
caution is about.

That is a pass, but it is a pass at the boundary rather than with margin.
Worth repeating **at a low state of charge**: as the cell droops the boost
draws more input current for the same output, so a start that succeeds on a
full cell is not proof of one on a nearly flat cell.

One thing still unmeasured: **a map write or delete under way.** Those hold the
USB host busy in a different pattern to a read sync and have not been measured
separately.

### Power path, confirmed

Applying USB-C power to the charger board **starts charging the cell while the
Nano stays running**. There is no drop-out, reset or re-enumeration at the
moment external power arrives, which is the simultaneous-charge-and-load and
seamless-handoff behaviour this section requires.

Only that direction has been tested. **Removing** external power and having the
cell take over without interrupting the P4 — the transition that actually
matters for a car that has just been switched off, and the one the state model
below depends on — has not been confirmed. Test it mid-sync, not idle: an
interruption there is the case with something to lose.

### Wiring the header

The 5 V rail is exposed on both 2x13 headers. On **P2**, the one nearest RESET,
pin 1 is 5 V and pin 3 is GND — adjacent in the same column, so it is a clean
two-wire tap. Pin 2 beside it is `ESP_LDO_VO4`, which is not a ground.

On **P1** the equivalents are pin 2 or pin 4 for 5 V and pin 6 for GND.

Disconnect USB-C before feeding the header. The board supplies `VCC_5V` through
a DIO7003 load switch fed from the USB-C port; injecting on the header bypasses
that switch, so two sources would be contending with nothing arbitrating. It
also means the board's own over-current protection is not in the path, so the
supply side owns that responsibility.

### Reference parts

A combination confirmed to power the Nano, tracked in issue #11:

| | |
| --- | --- |
| Charger, power path and boost | Adafruit 6106 — bq25185 with a TPS61023, 5 V at 1 A max |
| Cell | EEMB LP103454, 3.7 V 2000 mAh, 54 × 34 × 10.3 mm |

Take care ordering: Adafruit also sells a bq25185 board with a **3.3 V buck**
instead of the 5 V boost. That variant cannot power the Nano and cannot supply
USB-compliant VBUS to the AccessPort.

The cell does not fit the current 55 × 55 mm enclosure — it is 54 mm long, so
the interior is short by about 3 mm at 2 mm walls, before the board or the
display. A battery build needs a new enclosure regardless, to house the charger.

## Deterministic state model

```text
external power detected
    -> cancel pending sleep
    -> wake or boot
    -> start normal RevLink services

external power lost
    -> enter configurable grace period
    -> continue from battery
    -> finish or safely cancel active work
    -> flush and unmount storage as required
    -> stop USB, radio, display, and network services
    -> enter deep sleep

external power returns
    -> GPIO wake
    -> initialize hardware
    -> restore normal services
```

Recommended initial grace period: five minutes. The timer may be made
configurable later, but sleep must never begin while a file transaction,
device write, database commit, or firmware update is active.

If external power disappears during a write, the battery must provide enough
hold-up time to complete or explicitly abort the operation. A low-battery
threshold must take the safe-shutdown path without beginning new work.

## Development-board manual shutdown

Until switched-power sensing and the battery power path exist, the accepted
manual demo control is a two-second hold of the Waveshare board's `BOOT`
button on GPIO35. The firmware blocks new syncs, cooperatively cancels active
work, stops the logical USB host, unmounts microSD, and enters deep sleep.

This is soft power only. It does not remove the board supply and it cannot
physically isolate the current board's USB-A data or VBUS. Press `RST` or
cycle power to wake. The production board should use the same lifecycle
sequence, but trigger it from external-power loss or a dedicated action button
and use its physical USB link-control adapter.

## Current BOOT button bindings

One button, on GPIO35, labelled `BOOT` on the Waveshare board and brought out
to the left-hand side button on the printed case. Presses count as a group when
they land within 650 ms of each other.

| Gesture | What happens |
| --- | --- |
| **Double-press** | Shows how to reach the portal. If the Sidecar is running its own hotspot you get a scannable Wi-Fi QR code; if it has joined a network instead, you get its `revlink-<id>.local` address. |
| **Any press while that is showing** | Dismisses it and returns to the normal status screen. |
| **Two double-presses within 20 s** | Authorises formatting a microSD that responded but would not mount. Deliberately awkward — see the storage recovery section. |
| **Hold 2 s** | Safe shutdown: blocks new syncs, cancels active work cooperatively, stops the USB host, unmounts the card, then deep sleep. |

Waking is `RST` or a power cycle; the hold is soft power and does not remove
the board supply.

All of the display gestures need the optional OLED fitted. Without one the
firmware still works and the button still shuts down on a hold, but the QR and
the address have nowhere to appear — use the address the portal shows, or
mDNS.

The double-press exists because "what is this thing's address" is the question
every new user asks first, and answering it on the device is faster than
explaining mDNS.

The QR is a standard `WIFI:T:WPA;S:<ssid>;P:<password>;` join code built on the
device, so any phone camera handles it — there is no app and nothing is looked
up remotely. It necessarily contains the hotspot password, which is the point:
the hotspot is a local fallback for joining the Sidecar itself, and anyone able
to read the screen is already holding the device.

Accepted on hardware: the code renders on the SH1106 and scans from a phone.

## Planned two-button controls

Do not implement this behavior until the development-board button wiring has
been reviewed. The intended product interaction is:

- **Power/sleep:** hold for five seconds to request safe shutdown or sleep.
- **Eject:** deliberately close the current AccessPort host session and return
  the device to drive-idle/Gauges.

Neither action may interrupt an active sync, transfer, device write, delete,
atomic cache/manifest commit, or session-close recovery. A press during one of
those states must be ignored and surfaced through the display/status layer;
it must not silently cancel work. Eject must use the accepted initialized
session lifecycle and acknowledged `0x05`/`0x35` close. It must not substitute
a context-free close, USB reset, or abrupt root-port shutdown.

The current development firmware still uses a two-second `BOOT` hold. The
planned five-second threshold and separate eject control are roadmap
requirements, not current behavior. The onboard `RST` switch may be
hardwired reset-only, so a dedicated GPIO input may be required for the
prototype and final board.

The future button-map review must also consider a five-rapid-press `BOOT`
gesture that requests a bounded retry of preferred saved Wi-Fi networks. This
is a candidate, not a current binding. If retained, its press window,
acknowledgment, cancellation, and safety-lock behavior must be designed
together with shutdown, eject, recovery, and factory-reset gestures so short
presses cannot accidentally trigger destructive or disruptive actions.

## Prototype acceptance

1. Verify the chosen vehicle USB outlet actually turns off in the intended
   ignition state; some outlets remain powered or shut down after a delay.
2. Confirm the power-path controller carries the full active load without a
   reset while external power is connected.
3. Remove external USB and verify uninterrupted battery operation.
4. Confirm the grace timer starts once, cancels if power returns, and never
   interrupts active work.
5. Enter deep sleep and verify the USB-present signal wakes the P4.
6. Repeat across rapid ignition cycling and low-battery conditions.

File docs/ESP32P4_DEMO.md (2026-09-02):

# RevLink Sidecar ESP32-P4 demo

A runbook for recording or giving a live demonstration. Everything runs on the
Sidecar and its microSD card; nothing needs a network beyond the one the phone
and the Sidecar share.

## Before recording

1. Confirm a recent verified microSD backup exists after the latest meaningful
   sync. Follow [`SIDECAR_SD_BACKUP.md`](SIDECAR_SD_BACKUP.md) before any
   storage or recovery demonstration.
2. Power the ESP32-P4 and confirm the OLED reaches its ready state.
3. Attach exactly one AccessPort directly to the board's USB host port. Until
   the beta gate in
   [`SINGLE_ACCESSPORT_SAFETY.md`](SINGLE_ACCESSPORT_SAFETY.md) passes, do not
   demo through a hub that can expose more than one AccessPort.
4. Put the phone, tablet, or in-dash browser on the same Wi-Fi network.
5. Open `http://revlink-<last-8-mac>.local`.
6. If mDNS is unavailable on the client, use the IPv4 address shown during
   connection setup.
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

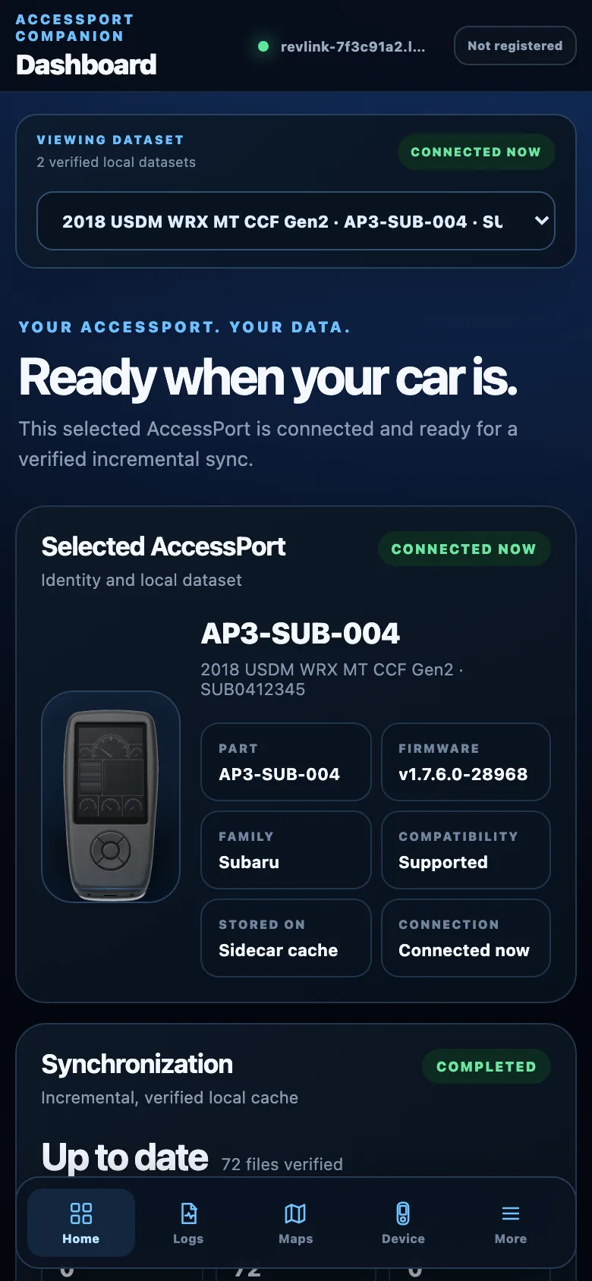
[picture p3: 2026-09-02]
web/site/assets/ui-dashboard.webp

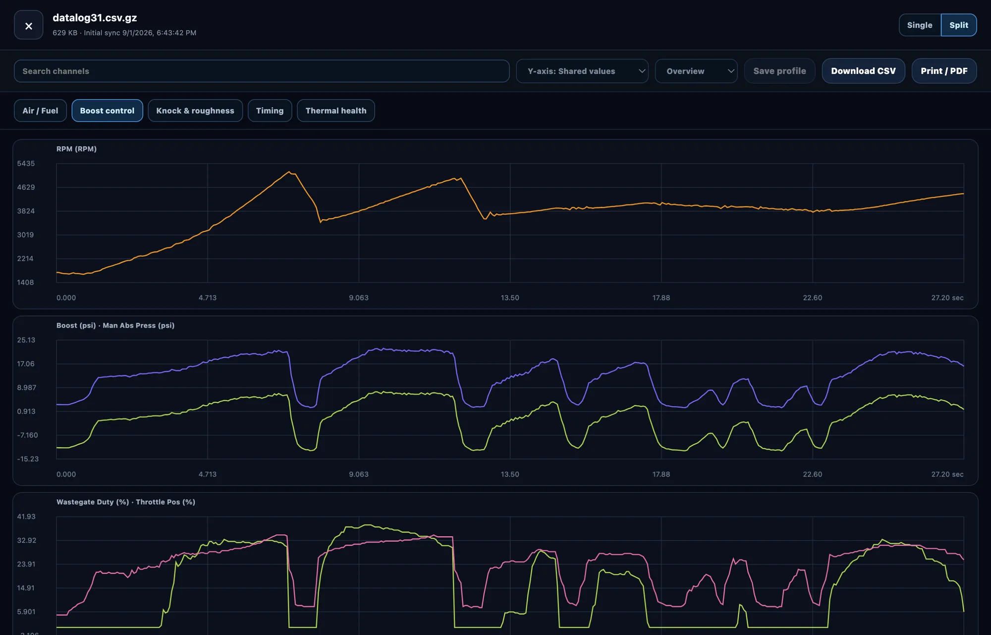
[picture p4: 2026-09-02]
web/site/assets/ui-graph.webp

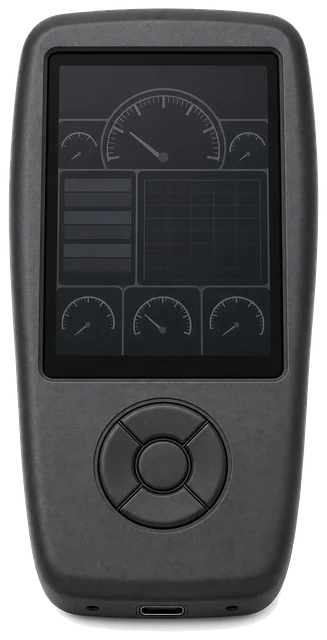
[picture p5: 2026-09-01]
firmware/esp32p4/main/portal/assets/accessport-render.webp

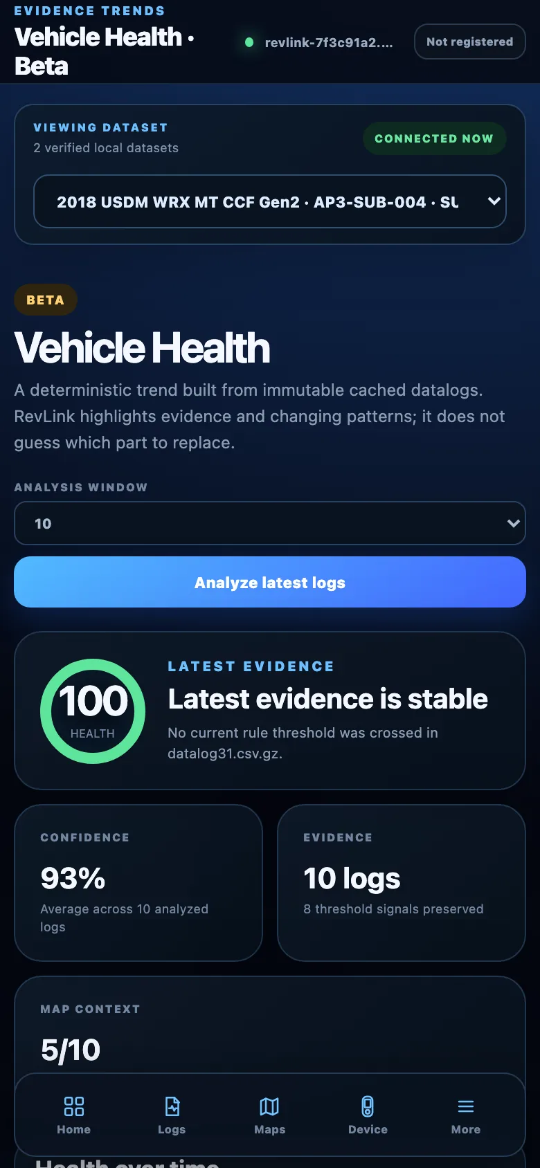
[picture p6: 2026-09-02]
web/site/assets/ui-health.webp

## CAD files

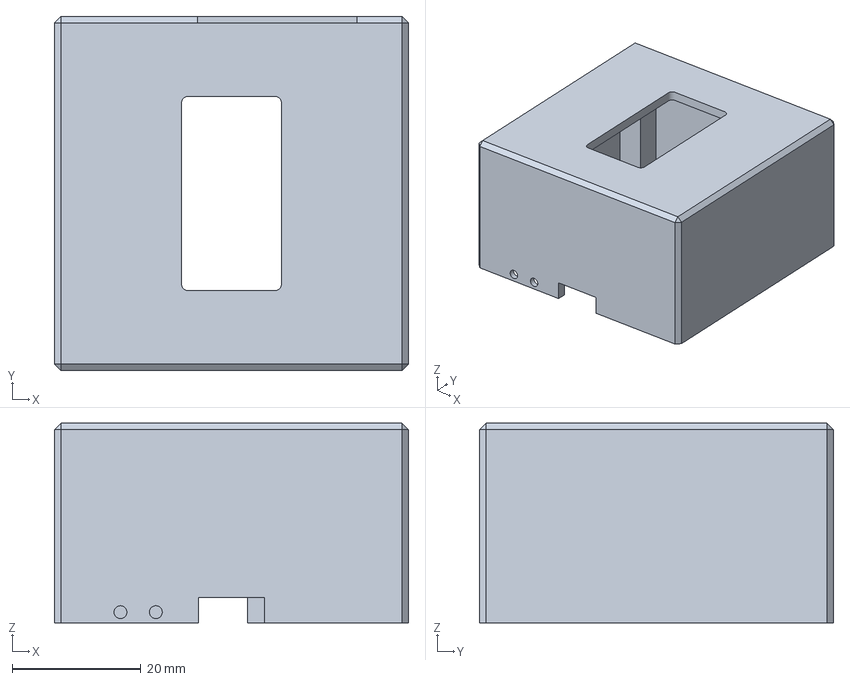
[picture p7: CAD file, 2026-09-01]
hardware/nano-enclosure/enclosure-print/print-package/02-revlink-sidecar-nano-top-oled-usbc-controls.3mf
55.0 x 55.0 x 31.0 mm

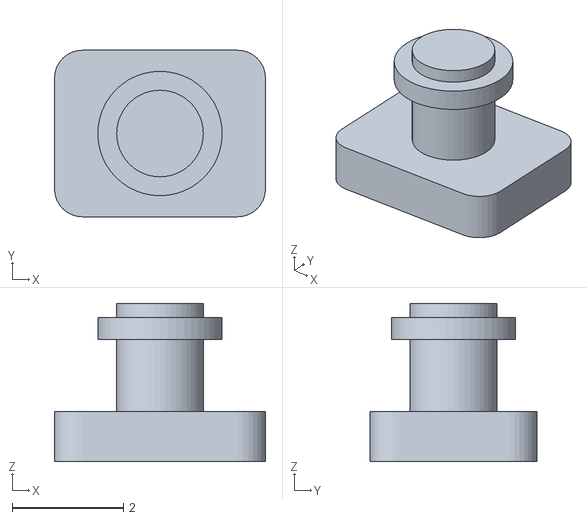
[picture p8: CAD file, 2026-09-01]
hardware/nano-enclosure/enclosure-print/revlink-sidecar-nano-usbc-side-button.stl
3.80 x 3.00 x 2.85

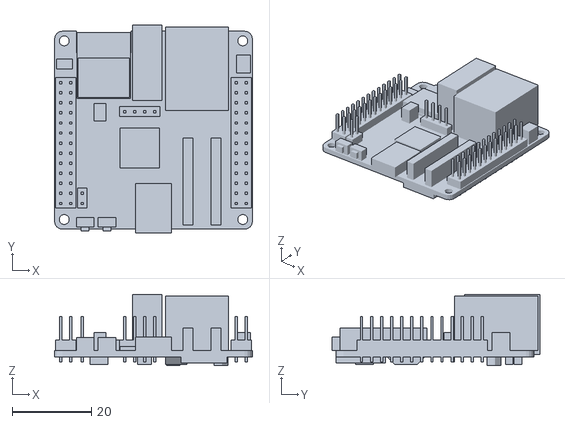
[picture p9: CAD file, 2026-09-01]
hardware/nano-enclosure/enclosure-print/source/esp32-p4-nano-board.stl
50.0 x 52.6 x 18.1

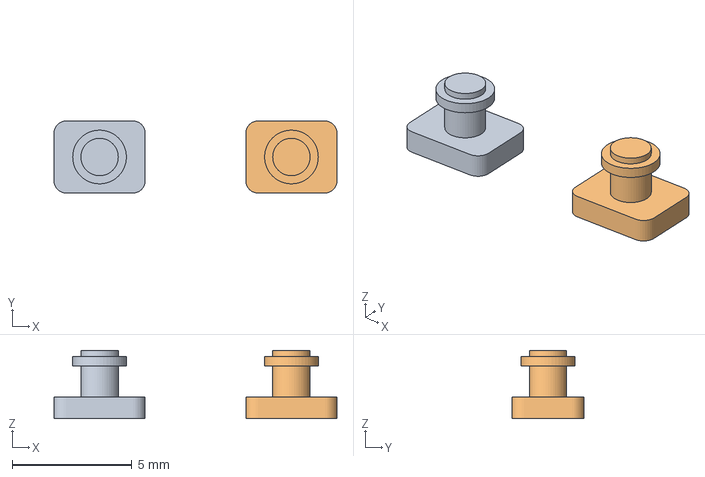
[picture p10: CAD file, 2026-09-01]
hardware/nano-enclosure/enclosure-print/print-package/03-revlink-sidecar-nano-usbc-side-buttons-pair.3mf
11.8 x 3.00 x 2.85 mm
RST side button
BOOT side button

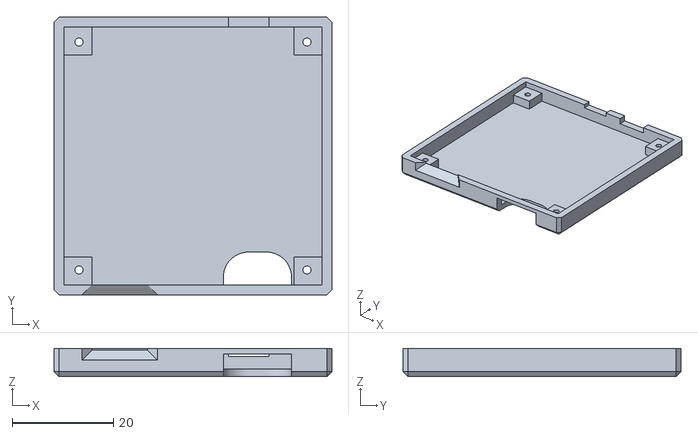
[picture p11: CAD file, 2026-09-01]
hardware/nano-enclosure/enclosure-print/source/esp32-p4-nano-bottom.stl
55.0 x 55.0 x 5.60

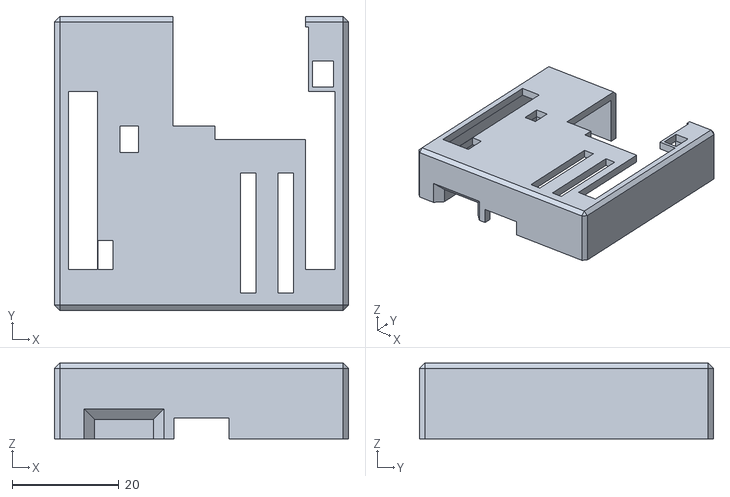
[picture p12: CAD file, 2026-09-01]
hardware/nano-enclosure/enclosure-print/source/esp32-p4-nano-top-solid.stl
55.0 x 55.0 x 14.2

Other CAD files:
hardware/nano-enclosure/enclosure-print/revlink-sidecar-nano-usbc-side-buttons.3mf
hardware/nano-enclosure/enclosure-print/print-package/01-revlink-sidecar-nano-bottom.3mf
hardware/nano-enclosure/enclosure-print/revlink-sidecar-nano-top-31mm-oled.3mf
hardware/nano-enclosure/enclosure-print/print-package/01-revlink-sidecar-nano-bottom.stl
hardware/nano-enclosure/enclosure-print/print-package/02-revlink-sidecar-nano-top-oled-usbc-controls.stl
hardware/nano-enclosure/enclosure-print/print-package/03-revlink-sidecar-nano-usbc-side-buttons-pair.stl
hardware/nano-enclosure/enclosure-print/revlink-sidecar-nano-top-31mm-oled.stl

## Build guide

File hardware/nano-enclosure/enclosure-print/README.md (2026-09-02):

# RevLink Sidecar ESP32-P4 Nano enclosure

> [!NOTE]
> This geometry has been printed and assembled successfully. The revised lid
> conceals the Ethernet jack, closes the donor case's switch slot and spare
> USB-A opening, and adds the OLED window and guided side buttons.
>
> Remaining refinement: add four internal OLED mounting legs/posts to the lid
> so the display PCB is positively located rather than retained by the window
> edge. Measure the physical OLED PCB, connector, solder joints, and wire exit
> before exporting new geometry.

This directory contains the Nano enclosure, a derivative of
["Waveshare ESP32-P4-NANO case and board model"](https://www.printables.com/model/1497431-waveshare-esp32-p4-nano-case-and-board-model)
by **MartinFaustMayer**, used under [CC BY 4.0](https://creativecommons.org/licenses/by/4.0/).
The unmodified donor STLs are kept in `source/` so the changes can be diffed.

Remixing and commercial use are permitted; the author must be credited. The
files in `source/` stay under CC BY 4.0.
RevLink's own modifications are CC BY-SA 4.0 — see `../../../NOTICE`, which
also carries the attribution.

## Open refinements

- [ ] Add four internal mounting legs/posts around the OLED opening.
- [ ] Confirm the supports retain the OLED PCB without touching the active
  display, connector, solder joints, or wiring.
- [ ] Regenerate the lid STL/3MF and record before/after `stl_inspect.py`
  output in the pull request.

## Revised lid

`revlink-sidecar-nano-top-31mm-oled.stl` and its matching `.3mf`:

- retain the donor lid's 55 × 55 mm footprint, mating edge, retaining clips,
  and connector clearances;
- increase the lid itself to exactly **31.0 mm** tall;
- retain the original **2.0 mm** roof thickness instead of stretching it;
- use a solid, smooth exterior roof;
- place a rounded **15.5 × 30.2 mm** portrait OLED window at the exact center
  of the lid; and
- expose only the required USB-A connector, with the extra upper opening
  closed;
- conceal the installed Ethernet jack behind a **0.8 mm** exterior wall with
  internal connector clearance;
- close the donor's large switch slot and provide guided side controls beside
  USB-C for the onboard **RST** and **BOOT** switches;
  and
- are closed, consistently wound manifold solids.

The OLED opening exposes the documented lit area of the existing 1.3-inch
SH1106 module. The larger 35.4 × 33.5 mm OLED PCB mounts behind the opening.

With the supplied 5.6 mm bottom, the modeled assembled enclosure height is
36.6 mm.

## Printed RST and BOOT buttons

`revlink-sidecar-nano-usbc-side-buttons.3mf` contains two identical,
pre-arranged side buttons: one for RST and one for BOOT. The matching
`revlink-sidecar-nano-usbc-side-button.stl` contains one universal button;
duplicate it once in the slicer.

Install both buttons from the USB-C edge before mating the lid and bottom.
Each button has:

- a low-profile **3.8 × 3.0 mm** rounded exterior cap;
- a short guided shaft aligned to the 2 × 2 mm side actuator; and
- a small retention flange to keep it captive after the fit-check.

Print the buttons in PETG for the slight compliance needed by the retention
flange. Verify free movement and switch return before fully closing the
enclosure.

## Printing

- Prefer PETG for an indoor fit-check and ASA for vehicle use.
- Start with 0.20 mm layers, four perimeters, five top/bottom layers, and
  25–35% infill.
- The supplied button STL and 3MF are already oriented cap-down. Print them at
  0.12–0.16 mm layers.
- Print one inexpensive fit-check before committing to the final material.
- Center the physical OLED's lit area behind the window before fixing the
  module in place.
- The STL is unitless by definition and is authored in millimeters. The 3MF
  records millimeter units explicitly.

## Rebuilding

The reproducible builder requires Python 3.11+, `numpy`, `trimesh`,
`manifold3d`, and `lxml`.

```sh
python build_oled_lid.py \
  --source source/esp32-p4-nano-top-solid.stl \
  --stl-output revlink-sidecar-nano-top-31mm-oled.stl \
  --3mf-output revlink-sidecar-nano-top-31mm-oled.3mf \
  --button-output revlink-sidecar-nano-usbc-side-button.stl \
  --button-3mf-output revlink-sidecar-nano-usbc-side-buttons.3mf
```

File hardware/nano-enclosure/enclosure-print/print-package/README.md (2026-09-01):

# RevLink Sidecar Nano print package

This folder contains exactly three printable part sets. Each is supplied in
both STL and 3MF format.

## 01 — Bottom

- `01-revlink-sidecar-nano-bottom.stl`
- `01-revlink-sidecar-nano-bottom.3mf`

One watertight body, 55 × 55 × 5.6 mm.

## 02 — Top with OLED and USB-C-side controls

- `02-revlink-sidecar-nano-top-oled-usbc-controls.stl`
- `02-revlink-sidecar-nano-top-oled-usbc-controls.3mf`

One watertight body, 55 × 55 × 31 mm. This is the corrected lid with the
centered OLED opening, concealed Ethernet jack, accessible USB-A and USB-C,
and two guided openings for the side-actuated RST and BOOT buttons.

## 03 — USB-C-side RST/BOOT button pair

- `03-revlink-sidecar-nano-usbc-side-buttons-pair.stl`
- `03-revlink-sidecar-nano-usbc-side-buttons-pair.3mf`

Two watertight button bodies arranged as a pair. The buttons are identical;
install one over RST and one over BOOT on the USB-C edge.

The 3MF versions are preferred for sending to the print service because they
record millimeter units explicitly.

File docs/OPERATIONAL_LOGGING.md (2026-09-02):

# Operational logging, retention, and support export

RevLink operational evidence exists to diagnose Sidecar behavior without
turning customer files, credentials, or vehicle data into an unbounded log.
This policy applies to the ESP32-P4 product firmware.

## Data classes

Keep these classes separate:

| Class | Examples | Default retention |
| --- | --- | --- |
| Volatile runtime diagnostics | component, severity, error code, bounded state transition | current boot only |
| Durable operational events | boot reason, firmware version, sync result counts, rollback result | bounded rotating history |
| Customer-owned data | datalogs, maps, screenshots, startup images, notes | dataset policy; never an operational log |
| Secrets | Wi-Fi passwords, session credentials, tokens, private keys | never logged |

Manifests and immutable object history are authoritative customer-data
metadata. They are not a substitute for operational logs, and operational logs
must not duplicate their file contents.

## ESP32-P4 policy

Normal `ESP_LOG*` output is volatile development evidence. Production builds
must suppress debug/verbose output and must never print:

- Wi-Fi passwords, HTTP authorization values, tokens, or cryptographic keys;
- datalog/map/image contents;
- complete request or response payloads from the AccessPort protocol;
- notes or diagnostic symptom text;
- full hardware MAC addresses or the internal `r1_...` identifier in routine
  logs; or
- a customer's complete file inventory.

When durable operational events are implemented, store them in a separate
versioned, checksummed, rotating file under
`/sdcard/revlink/system/events/`. Use at most four 256 KiB segments and rotate
oldest first. Each record should contain only:

- schema version and monotonic sequence;
- UTC timestamp plus time-source/quality when trusted time exists;
- boot/session-local monotonic milliseconds;
- firmware version and reset reason;
- stable event code and severity;
- bounded numeric counters or public state names; and
- a redacted correlation ID that is random per support export.

Do not place durable logs in NVS or internal flash. This avoids flash wear and
keeps removable customer data under an explicit retention boundary. Logging
failure must not block local sync, browsing, safe close, or shutdown.

The reserved coredump partition remains disabled until the same redaction,
bounded retention, export, and explicit erase rules are implemented.

## Support bundle

A support bundle is customer-initiated and local-only by default. Creating one
must require an explicit UI action and show exactly what will be included.
The initial format should be a ZIP containing:

- a human-readable summary with firmware/build, reset reason, network mode,
  storage health, and USB endpoint contract;
- the bounded durable operational event segments;
- current configuration values with secrets omitted;
- manifest counts and integrity status, not customer filenames or file
  contents; and
- an inclusion manifest with SHA-256 for every exported file.

Exclude datalogs, maps, images, notes, credentials, MAC addresses, the internal
Sidecar ID, AccessPort serial numbers, IP addresses, and SSIDs by default.
Customer-owned files require a separate, explicit selection and consent step.
Never upload a bundle automatically. Future cloud support upload must disclose
destination and retention before consent and must use authenticated encrypted
transport.

## Erase and recovery

- Rotating operational events can be erased independently of customer data.
- Factory reset must state whether operational evidence is erased; it must
  never silently erase the microSD dataset.
- A corrupt event segment is quarantined or skipped. It must not trigger
  formatting, manifest repair, or deletion of customer files.
- Removing or replacing the microSD card simply makes durable operational
  history unavailable. The Sidecar continues with volatile logging and a clear
  storage-health state.

## Audit logs that ship today

Two exceptions to "operational logging is volatile" already exist. Every
device write and every device delete is appended to the card *before* the
outcome is reported anywhere else, because an irreversible action on somebody
else's hardware with no record is worse than a log file:

```text
/sdcard/revlink/system/acceptance/map-write-audit.log
/sdcard/revlink/system/acceptance/file-delete-audit.log
```

One line per operation: UTC timestamp, AccessPort part number and serial, the
path, the outcome, the platform error code, and whether recovery is required.

Three properties worth knowing before you rely on them:

- **They are not rotated.** They grow without bound. In normal use that is a
  few bytes per deliberate write or delete, but nothing trims them.
- **They are not in a logical backup.** The backup export walks
  `/sdcard/revlink/devices`; these live under `/sdcard/revlink/system`, so
  they do not travel with a card backup and are lost with the card.
- **They contain device identifiers** — part number and serial — which is the
  point, and which is also why they are the one thing on the card to redact
  before sharing a log with anyone.

## Acceptance before durable logging ships

Host and hardware tests must prove:

1. rotation never exceeds the configured byte/segment limits;
2. power loss during append preserves previous valid records;
3. malformed segments do not affect customer manifests;
4. redaction fixtures contain no known secret, identifier, filename, note, or
   payload sample;
5. export inclusion manifests match bundle bytes;
6. erase removes only operational evidence; and
7. a full or absent microSD does not prevent safe device close or shutdown.

Until these tests pass, keep production operational logging volatile and use
the existing manifests as the only persistent sync evidence.

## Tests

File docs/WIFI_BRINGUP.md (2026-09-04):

# ESP32-C6 radio coexistence bring-up

This document records the radio and storage coexistence work the shipping
network manager was built on, and the live acceptance runs that cleared it.

The runs below were performed on the Waveshare ESP32-P4-WIFI6-DEV-KIT. The
published firmware targets the ESP32-P4-NANO; the GPIO assignments here are
firmware constants and are the same on both boards, but header pin positions
are not — see [`OLED_BRINGUP.md`](OLED_BRINGUP.md).

For the current state of the network stack rather than how it was accepted,
see [`ACCEPTANCE_LOG.md`](ACCEPTANCE_LOG.md).

## Resource ownership

| Subsystem | Controller | Signals |
| --- | --- | --- |
| ESP32-C6 Wi-Fi/BLE coprocessor | P4 SD/MMC host, 4-bit SDIO | CLK 18, CMD 19, D0-D3 14-17, reset 54 |
| microSD | SPI3 | CLK 43, MOSI/CMD 44, MISO/D0 39, CS/D3 42 |
| SH1106 OLED | SPI2 | CLK 23, MOSI 22, CS 21, D/C 20, reset 2 |
| AccessPort | USB 2.0 high-speed host | USB-A OTG host port |

The ESP32-P4 has one SD/MMC controller. The C6 and native four-bit microSD
cannot own it simultaneously. The radio profile therefore keeps the radio on
its board-routed SDIO link and moves only the removable card to SPI3. Storage
layout, device namespaces, immutable objects, manifests, and sync behavior do
not change.

## Build profiles

The default profile explicitly disables ESP-Hosted and remote Wi-Fi:

```text
# CONFIG_ESP_WIFI_REMOTE_ENABLED is not set
# CONFIG_ESP_HOSTED_ENABLED is not set
# CONFIG_REVLINK_WIFI_SCAN_ACCEPTANCE is not set
# CONFIG_REVLINK_SD_SPI_TRANSPORT is not set
```

The bounded radio profile is selected only through
`sdkconfig.wifi-scan.defaults`:

```text
CONFIG_REVLINK_WIFI_SCAN_ACCEPTANCE=y
CONFIG_REVLINK_SD_SPI_TRANSPORT=y
CONFIG_ESP_WIFI_REMOTE_ENABLED=y
CONFIG_ESP_HOSTED_ENABLED=y
```

The integrated coordinator acceptance profile layers
`sdkconfig.wifi-join.defaults` and
`sdkconfig.network-runtime.defaults` on top. It enables the RAM-only station
adapter, fallback SoftAP, development console, OLED, SPI3 microSD, USB host,
and runtime sync while keeping AccessPort writes disabled:

```sh
idf.py -C firmware/esp32p4 \
  -B firmware/esp32p4/build-network-runtime \
  -D "SDKCONFIG=$PWD/firmware/esp32p4/build-network-runtime/sdkconfig" \
  -D 'SDKCONFIG_DEFAULTS=sdkconfig.defaults;sdkconfig.oled.defaults;sdkconfig.wifi-scan.defaults;sdkconfig.wifi-join.defaults;sdkconfig.network-runtime.defaults' \
  build
```

Build both profiles when changing storage, radio, or managed-component
dependencies:

```sh
source "$HOME/.espressif/frameworks/esp-idf-v6.0.2/export.sh"

idf.py -C firmware/esp32p4 \
  -B build-radio-off \
  -D SDKCONFIG="$PWD/build-radio-off/sdkconfig" \
  -D 'SDKCONFIG_DEFAULTS=sdkconfig.defaults;sdkconfig.oled.defaults' \
  reconfigure build

idf.py -C firmware/esp32p4 \
  -B build-wifi-scan \
  -D SDKCONFIG=sdkconfig.wifi-scan \
  -D 'SDKCONFIG_DEFAULTS=sdkconfig.defaults;sdkconfig.oled.defaults;sdkconfig.wifi-scan.defaults' \
  reconfigure build
```

The radio-off binary must contain no C6 scan or ESP-Hosted runtime strings.
The radio-on configuration must show all four profile options enabled.

## Live acceptance

The combined profile passed on the physical board on 2026-07-27:

1. A true board power cycle allowed the existing card to enter SPI mode.
2. The C6 initialized over 4-bit SDIO at 40 MHz with 512-byte blocks.
3. The 64 GB microSD mounted over SPI3 without formatting and retained the
   existing acceptance marker and cached dataset.
4. A bounded anonymous scan found six access points. Only count, strongest
   RSSI, and channel were retained; no identities or credentials were logged.
5. The AccessPort enumerated at USB high speed with 512-byte file endpoints.
6. A read-only incremental sync found 33 candidates, verified 33 cache hits,
   downloaded zero files, and left zero pending.
7. The polite `0x05` close received `0x35`; the AccessPort detached,
   re-enumerated, and returned to available.
8. Writes, deletes, formatting, and automatic sync remained disabled.

## Ephemeral station-join acceptance

The controlled connection profile passed live on 2026-07-27:

- the SSID and password entered through the local UART console were never
  echoed or logged;
- `esp_wifi_set_storage(WIFI_STORAGE_RAM)` kept station configuration out of
  NVS and microSD;
- the ESP32-C6 associated with the selected development network;
- DHCP completed;
- a fixed `example.com` DNS lookup completed, proving bidirectional IP
  traffic through the hosted radio; and
- AccessPort writes remained uncompiled and automatic sync remained off.

The successful terminal result was:

```text
C6 NETWORK ACCEPTANCE PASSED: association, DHCP, and DNS traffic
wifi acceptance: PASS (association + DHCP + DNS)
```

This test uses a separate `wifi-join` profile and the local-only
`wifi-join` console command:

```sh
source "$HOME/.espressif/frameworks/esp-idf-v6.0.2/export.sh"
idf.py -C firmware/esp32p4 \
  -B build-wifi-join \
  -D SDKCONFIG=sdkconfig.wifi-join \
  -D 'SDKCONFIG_DEFAULTS=sdkconfig.defaults;sdkconfig.oled.defaults;sdkconfig.wifi-scan.defaults;sdkconfig.wifi-join.defaults' \
  set-target esp32p4 build
```

ESP-Hosted still reports `Host [2.12.0] > Co-proc [0.0.0]`, but the actual
association, DHCP, and DNS path passed. Do not update the C6 solely to remove
that warning; revisit its firmware only if a required RPC fails reproducibly.

## Coordinator and fallback-hotspot acceptance

The first integrated product-network slice passed live on 2026-07-27:

- the platform-neutral coordinator started above the P4/C6 radio adapter;
- with no RAM-only station record, it selected fallback mode without scanning
  continuously;
- it waited in `hotspot-starting` until an explicit local credential was
  supplied;
- credential input was hidden, remained in RAM, and was excluded from logs
  and public snapshots;
- the C6 started a WPA2 SoftAP named
  `RevLink-<last six AP-MAC digits>` on channel 6;
- the default ESP-IDF AP netif started its private DHCP service;
- the coordinator reached `hotspot-ready`; and
- the 64 GB microSD, OLED, USB host, and attached AccessPort remained active,
  with device writes disabled.

The development console adds these local-only acceptance commands:

```text
wifi-status
wifi-hotspot
wifi-fallback
wifi-join
```

`wifi-status` deliberately exposes states, configuration flags, client count,
transfer lock, and error code without exposing a saved network identity or
credential. Credentials are not retained across reset in this profile.

## Reset caveat

SPI mode is selected during card initialization. A CPU reset can leave the
removable card powered in its previous native SD mode, and the on-chip LDO
software cycle did not reliably reset it on this development board. When
switching an already-running card between native SD and SPI profiles, use a
true board power cycle. Normal boots within one profile do not change the
filesystem or format the card.

## What has since shipped

Most of what this document once listed as future work is in the published
firmware: the onboarding HTTP service on port 80, bounded captive DNS and
captive-probe routes, a unique mDNS hostname, a persistent station credential
store, and the setup and forget flows. Provisioning sits behind a local
boundary — a hardware-RNG hotspot password shown only on the OLED.

The coordinator's station selection, reconnect, fallback, explicit retry,
force-hotspot and transfer-lock behaviour are implemented as a state machine in
`revlink_network`. [`ACCEPTANCE_LOG.md`](ACCEPTANCE_LOG.md) records what was
accepted and when.

## Remaining work

- **The credential store is not encrypted.** A station credential is saved as a
  versioned NVS record only after a successful association, and a failed
  candidate never replaces the last working record — but that record is
  plaintext. Encrypted NVS, flash encryption, and secure boot are required
  before it counts as a shipping security boundary.
- **BLE is not implemented.** Should it be added, it belongs behind a separate
  authenticated adapter and its own acceptance gate, scoped to discovery,
  provisioning, connectivity recovery, and compact status. All file transfer
  stays on Wi-Fi.
- The coordinator's failure matrix — wrong password, link loss, explicit retry,
  force-hotspot, transfer-lock contention — is exercised in normal use but has
  not been live-accepted exhaustively as a matrix.
- Never log SSIDs, BSSIDs, or passwords. This holds for anything added later.

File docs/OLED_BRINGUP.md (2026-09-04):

# RevLink SH1106 OLED bring-up

This is the reviewed harness for the existing 1.3-inch, seven-pin SPI SH1106
OLED and the Waveshare **ESP32-P4-NANO**, which is the board the published
firmware targets.

Header pin numbers below are for that board. The ESP32-P4-WIFI6-DEV-KIT places
the same GPIOs on different header positions, so do not carry these pin numbers
across to it.

## Safety

- Disconnect all power before moving jumpers.
- Power the OLED from **3V3**, not 5V.
- Match the printed labels on both boards; do not rely on wire color.
- Leave the microSD card and USB host wiring unchanged.
- If any label differs from the table, stop and verify the module before
  applying power.

## Wiring

`P1` is the 2x13 header away from RESET, `P2` the one nearest it. Pin 1 is at
the top of both, and odd pins are the column nearest the board edge.

| OLED label | GPIO | Header pin | Function |
| --- | --- | --- | --- |
| `GND` | — | `P1` 9 | Common ground |
| `VCC` | — | `P1` 17 | Display power, 3V3 |
| `CLK` | `23` | `P1` 7 | SPI clock |
| `MOSI` | `22` | `P1` 16 | SPI data |
| `RES` | `2` | **`P2` 11** | Display reset |
| `DC` | `20` | `P1` 13 | Data/command select |
| `CS` | `21` | `P1` 15 | Chip select |

**`RES` is the only wire on `P2`.** Six of the seven land on `P1`, so a display
that stays dark after a reconnection is worth checking there first.

Ground and 3V3 are the two rows with a choice. `P1` carries ground on pins 6, 9,
14, 20 and 25, and 3V3 on pins 1 and 17; the table picks 9 and 17 to leave pins
1, 3, 5 and 6 contiguous for the fuel gauge in #17, which needs 3V3, `SDA`,
`SCL` and a ground of its own.

```text
OLED SH1106                       ESP32-P4 header

 GND  o------------------------------o GND      P1 pin 9
 VCC  o------------------------------o 3V3      P1 pin 17
 CLK  o------------------------------o GPIO23   P1 pin 7
 MOSI o------------------------------o GPIO22   P1 pin 16
 RES  o------------------------------o GPIO2    P2 pin 11
 DC   o------------------------------o GPIO20   P1 pin 13
 CS   o------------------------------o GPIO21   P1 pin 15
```

The selected GPIOs avoid the accepted microSD bus (`39`–`44`), ESP32-C6 SDIO
link (`14`–`19`), audio signals (`9`–`13`), ESP32-P4 strapping pins
(`34`–`38`), and the USB host peripheral.

## Expected first boot

1. The portal-style RevLink mark animates in beside the `REVLINK` wordmark,
   with the running firmware version below it as `V0.2.5` and a progress bar
   filling underneath. It holds for 1.5 s.
2. With no AccessPort attached the screen settles on
   `NO DEVICE / ACCESSPORT OFFLINE / CONNECT TO SYNC`.
3. Attaching one moves it to `CHECKING / ACCESSPORT / USB HIGH SPEED`, then to
   the ready screen, which shows the vehicle and part number rather than fixed
   text.
4. A sync shows `SYNCING / BACKING UP LOGS / KEEP CONNECTED` with progress.
5. A finished sync ends on `BACKUP COMPLETE / SAFE TO DISCONNECT`.

The display is output-only. It cannot authorize a write, initiate a sync, or
bypass any safety gate.

## Every screen

The status screens share a layout: a header that alternates between `REVLINK`
and `SIDECAR`, a Wi-Fi icon and network badge top-right when a network is up,
then a headline, a detail line and a footer. The headline drops from the large
font to the small one automatically if it is too wide.

The badge says where the portal is: `LOCAL` while the Sidecar is running its
own hotspot, the network's SSID once it has joined one, or `WIFI` if the SSID
is unavailable. A long SSID is truncated to fit.

| State | Headline | Detail | Footer |
| --- | --- | --- | --- |
| Booting | `STARTING` | `SYSTEM CHECK` | `REVLINK` |
| No device | `NO DEVICE` | `ACCESSPORT OFFLINE` | `CONNECT TO SYNC` |
| Inspecting | `CHECKING` | `ACCESSPORT` | `USB HIGH SPEED` |
| Ready | vehicle, or `DEVICE CONNECTED` | part number | `READY TO SYNC` |
| Sync queued | `SYNC QUEUED` | `PREPARING BACKUP` | `PLEASE WAIT` |
| Syncing | `SYNCING` | `BACKING UP LOGS` | `KEEP CONNECTED` |
| Session open | `CONNECTED` | `SESSION ACTIVE` | `KEEP CONNECTED` |
| Cancelling | `FINISHING` | `CLOSING SAFELY` | `KEEP CONNECTED` |
| Recovering | `RECOVERING` | `SAFE USB CLOSE` | `KEEP CONNECTED` |
| Complete | vehicle, or `SYNC COMPLETE` | `BACKUP COMPLETE` | `SAFE TO DISCONNECT` |
| Wi-Fi dropped | `WIFI LOST` | `RETRY <n> SEC`, or `RETRYING` with no countdown | `HOTSPOT NEXT` |
| USB fault | `ATTENTION` | `USB NEEDS CHECK` | `OPEN REVLINK` |
| Sync fault | `ATTENTION` | `SYNC NEEDS CHECK` | `OPEN REVLINK` |
| Two AccessPorts | `MULTIPLE DEVICES` | `UNPLUG ALL DEVICES` | `THEN RECONNECT ONE` |
| Unknown | `ATTENTION` | `STATUS UNKNOWN` | `OPEN REVLINK` |

Four screens replace that layout entirely rather than sitting inside it:

| Screen | Shown when | Contents |
| --- | --- | --- |
| Hotspot details | The fallback hotspot comes up | `REVLINK SETUP`, the SSID, `PASSWORD`, the password |
| Wi-Fi QR | BOOT double-press while the hotspot is up | A scannable `WIFI:T:WPA;…` join code |
| Local address | BOOT double-press while joined to a network | `OPEN IN BROWSER`, the hostname, `.local`, `PRESS TO CLOSE` |
| Storage recovery | The card is missing or will not mount | See below |

## Storage recovery screens

These are the only screens that ask for input, and they are deliberately
awkward because the outcome is destructive.

| Step | Screen |
| --- | --- |
| No card | `SD CARD MISSING` / `INSERT A CARD` / `THEN RESTART` |
| Card unreadable | `SD UNREADABLE` / `DOUBLE-PRESS BOOT` / `TO FORMAT` |
| Awaiting confirmation | `ERASE SD CARD?` / `ALL DATA WILL BE LOST` / `DOUBLE-PRESS BOOT` / `CONFIRM IN <n> SEC` |
| Formatting | `FORMATTING SD` / `DO NOT POWER OFF` |
| Done | `FORMAT COMPLETE` / `STORAGE READY` / `RESTARTING` |
| Failed | `FORMAT FAILED` / `CHECK SD CARD` / `THEN TRY AGAIN` |
| Other error | `STORAGE ERROR` / `CHECK SD CARD` / `THEN RESTART` |

Formatting requires two separate double-presses, the second within the
countdown. One accidental double-press cannot erase a card.

## Bench build

The overlay is `firmware/esp32p4/sdkconfig.oled.defaults`. It enables runtime
read-only sync, USB root-port power, and the OLED while leaving device writes,
all acceptance tests, and SD formatting disabled.

```sh
source "$HOME/.espressif/frameworks/esp-idf-v6.0.2/export.sh"
idf.py -C firmware/esp32p4 \
  -B firmware/esp32p4/build-oled \
  -D SDKCONFIG=sdkconfig.oled \
  -D 'SDKCONFIG_DEFAULTS=sdkconfig.defaults;sdkconfig.oled.defaults' \
  set-target esp32p4 build
```

## Live acceptance

The complete display path passed on the physical prototype on 2026-07-27:

- the firmware flashed and passed SHA verification;
- the SH1106 initialized on the reviewed SPI pinout;
- the RevLink splash and status layout rendered at the correct orientation
  and usable size;
- the 64 GB microSD remained mounted without formatting;
- the attached AccessPort enumerated at high speed with 512-byte file
  endpoints and drove the display from `inspecting` to `available`; and
- device writes, automatic sync, destructive acceptance tests, and SD
  formatting remained disabled.

The application image was about 1.34 MB in a 4 MiB app slot.

## One-run sync demonstration

`firmware/esp32p4/sdkconfig.oled-sync.defaults` combines the accepted display
with the normal bounded read-only runtime sync and the accepted PC-mode exit
path. It forces one sync regardless of saved policy, renders its progress,
performs the acknowledged `0x05`/`0x35` close, and stops the logical USB root
port. It does not enable AccessPort writes, deletes, formatting, or live-data
commands.

This complete visual workflow passed on the physical prototype on 2026-07-27:

```text
device: waiting -> inspecting -> available -> session-active -> available
sync:   queued -> running -> completed
logs:   33 candidates, 33 verified cache hits, 0 downloads, 0 pending
close:  subtype 0x05 sent, subtype 0x35 acknowledged
USB:    software detach observed, logical root port stopped with ESP_OK
```

The normal OLED image was restored afterward with auto-sync disabled and all
acceptance gates and device writes disabled.

## Live UART-driven sync acceptance

The normal OLED bench image also exposes the fixed development control
grammar over the programming USB UART. On 2026-07-27 the board accepted
`status`, then completed a manually requested `sync`, then returned this
terminal snapshot:

```text
status=ok device=available sync=completed auto=off progress=33/33
downloaded=0 skipped=33 pending=0 writes=locked shutdown=no
```

The sync performed the same acknowledged `0x05`/`0x35` close as the one-run
visual demonstration, but kept the normal USB host active. The AccessPort
software-re-enumerated at high speed and returned to the descriptor-ready
`available` state. The console remained quiet while idle after its
nonblocking input loop was accepted.

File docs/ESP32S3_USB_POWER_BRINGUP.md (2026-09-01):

# ESP32-S3 USB host power bring-up

> **Archived feasibility record — do not use as an active build or bring-up
> plan.** The ESP32-S3 target was retired on 2026-07-26 after its full-speed
> USB controller failed the required endpoint gate. ESP32-P4 is the sole
> consumer-firmware target. Do not spend time maintaining S3 compatibility or
> designing a companion high-speed host for it.

The generic ESP32-S3-N16R8 development board has separate `COM` and native
`USB` USB-C connectors. The native connector routes USB D+/D- to the ESP32-S3,
but its ability to act as a safe 5 V downstream power source is unverified.

Do not use the AccessPort as the first electrical load. A visible 5 V reading
with no load does not prove that the connector can safely power it.

## Live result — 2026-07-25

A known-good powered USB adapter successfully supplied the AccessPort and
passed USB data to the ESP32-S3 native host. The AccessPort booted normally
and enumerated at full speed as VID/PID `1a84:0121`.

The descriptor-only firmware read all four standard configuration
descriptors. Every full-speed descriptor exposed only `0x02` OUT and `0x81`
IN with 64-byte maximum packets. None exposed the proven file-channel
endpoints `0x03` OUT and `0x82` IN. No interface was claimed and no
proprietary or storage request was sent.

This result proved the prototype power path, D+/D- path, ESP32-S3 host role,
and basic enumeration. It also failed the file-channel feasibility gate for
the ESP32-S3 native full-speed controller. The subsequent ESP32-P4 experiment
provided the required high-speed host. The S3 is not retained as a
Wi-Fi/application controller.

## Known facts

- The native connector is the only connector suitable for the ESP32-S3
  internal USB host controller.
- The board has no visibly identified USB high-side power switch,
  current-limit controller, or over-current signal.
- The board is an unidentified DevKitC-style clone, so the official Espressif
  schematic is only a reference, not proof of this board's wiring.
- A read-only query on the development Pi reports `MaxPower 2mA` in all four
  AccessPort USB configurations. This descriptor value is not credible as the
  device's actual operating current and must not be used to size the supply.
- An inline USB meter measurement on 2026-07-25 captured the following
  AccessPort states on a known-good source:
  - disconnected baseline: `4.97 V`, `0.00 A`, `0.00 W`;
  - startup/help screen: `4.98 V`, `0.12 A`, `0.58 W`;
  - running/menu screen: `4.98 V`, `0.08 A`, `0.39 W`; and
  - later menu state: `4.93 V`, `0.04 A`, `0.19 W`.
  The largest captured draw was therefore about 120 mA. Still treat this as an
  observed operating value rather than a guaranteed inrush maximum because
  the meter/video sampling rate may miss short transients.

## Required equipment

Preferred:

- USB-C breakout or known-good USB power meter that exposes VBUS and GND;
- adjustable USB electronic load;
- inline USB current meter for measuring the AccessPort on the Pi; and
- current-limited 5 V bench supply or protected powered USB source.

A multimeter can establish continuity and no-load voltage, but it cannot prove
the port is safe under startup load.

## Test sequence

### 1. Map the unpowered board

Disconnect both USB connectors and everything on the headers.

1. Check continuity/diode behavior between native-USB VBUS and the board's 5 V
   header.
2. Check between native-USB VBUS and COM-port VBUS.
3. Check that native-USB GND and board GND are common.
4. Record both meter polarity readings; a diode path in one direction matters.

Do not inject voltage during continuity or diode mode.

### 2. Measure no-load VBUS

Power only the `COM` connector. Leave the AccessPort disconnected.

1. Measure native-USB VBUS to GND.
2. Reverse the USB-C plug orientation and repeat.
3. Pass range: 4.75–5.25 V in both orientations.

Zero volts means the onboard connector cannot source VBUS in this arrangement.
Five volts permits load testing but is not yet an approval to attach the
AccessPort.

### 3. Apply a protected dummy load

Use an electronic load, beginning at zero current:

1. 50 mA for 30 seconds;
2. 100 mA for 60 seconds;
3. 250 mA for 60 seconds; and
4. only after measuring the real AccessPort current, its observed startup peak
   plus at least 25% margin.

For the current measured unit, 150 mA is 25% above the largest captured
120 mA reading. The development path should nevertheless pass the existing
250 mA step, and a protected 5 V source rated for at least 500 mA is the
minimum practical prototype target. A 1 A current-limited source provides
additional bring-up margin without changing the AccessPort's actual demand.

At every step record:

- VBUS at the native connector;
- load current;
- COM-source input current;
- ESP32 resets or serial disconnects; and
- unexpected heating at the connectors, diodes, traces, or regulator.

Stop immediately if VBUS drops below 4.75 V, the board resets, the source
current-limits, or any component heats rapidly. Do not jump directly to a
500 mA load.

### 4. Measure the AccessPort on the known-good Pi

Place an inline USB meter between the Pi and AccessPort and record:

- unplugged baseline;
- startup peak;
- steady idle current;
- screen-on current; and
- peak during directory listing and file transfer.

The USB descriptor's reported 2 mA is not a substitute for these measurements.

### 5. First AccessPort power-only test

Only after the dummy-load test exceeds the measured AccessPort peak:

1. use a current-limited source and inline meter;
2. leave ESP32 USB-host transactions disabled;
3. connect the AccessPort and observe startup;
4. confirm VBUS stays in range and the ESP32 does not reset; and
5. disconnect at the first sign of brownout or heating.

This proves power-up only. It does not prove USB host role signaling,
enumeration, or data reliability.

### 6. Enumeration test

Before the AccessPort, flash the read-only USB-host enumeration firmware and
test with an inexpensive low/full-speed USB peripheral. Then connect the
AccessPort and record:

- VID/PID `1a84:0121`;
- negotiated speed;
- active configuration;
- interface `0`;
- bulk OUT `0x03` and bulk IN `0x82`; and
- active endpoint maximum packet sizes.

No storage request should be transmitted during the first enumeration test.

This test was completed on 2026-07-25. VID/PID and full-speed enumeration
passed, but the required `0x03/0x82` endpoint pair was absent from all four
full-speed configuration descriptors. Do not proceed to an interface claim
or root-directory request on this native host.

## Expected product solution

Even if the development board happens to backfeed 5 V successfully, that is
not a production-quality host supply. The product design should provide a
dedicated protected 5 V VBUS path with:

- a current-limited high-side/load switch;
- reverse-current blocking;
- controlled enable;
- over-current/fault reporting;
- local bulk and high-frequency decoupling; and
- enough startup-current margin for the AccessPort.

For prototype USB data testing, use a properly powered host adapter, power
injector, or powered hub rather than relying on an unidentified board trace.

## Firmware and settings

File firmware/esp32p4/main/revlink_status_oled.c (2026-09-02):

#include "revlink_status_oled.h"

#include <stdbool.h>
#include <stdint.h>
#include <stdio.h>
#include <string.h>

#include "driver/gpio.h"
#include "driver/spi_master.h"
#include "esp_check.h"
#include "esp_app_desc.h"
#include "esp_log.h"
#include "esp_log_level.h"
#include "esp_timer.h"
#include "freertos/FreeRTOS.h"
#include "freertos/task.h"
#include "qrcode.h"
#include "revlink_oled_render.h"
#include "revlink_status_model.h"

/* One source of truth for the panel geometry: the renderer's. */
#define OLED_WIDTH REVLINK_OLED_WIDTH
#define OLED_HEIGHT REVLINK_OLED_HEIGHT
#define OLED_PAGES REVLINK_OLED_PAGES
#define OLED_BUFFER_SIZE REVLINK_OLED_BUFFER_SIZE
#define OLED_SPI_HOST SPI2_HOST
#define OLED_PIN_SCLK GPIO_NUM_23
#define OLED_PIN_MOSI GPIO_NUM_22
#define OLED_PIN_CS GPIO_NUM_21
#define OLED_PIN_DC GPIO_NUM_20
#define OLED_PIN_RESET GPIO_NUM_2
#define OLED_CLOCK_HZ (8 * 1000 * 1000)
#define OLED_TASK_PERIOD_MS 100U
#define OLED_SPLASH_MS REVLINK_OLED_SPLASH_MS
#define OLED_HEADER_CYCLE_TICKS 150U
#define OLED_SIDECAR_WINDOW_TICKS 30U
#define OLED_CONNECTED_SSID_CAPACITY 33U
#define OLED_NETWORK_BADGE_CAPACITY 13U
#define OLED_NETWORK_BADGE_VISIBLE_CHARS 12U
#define OLED_QR_TIMEOUT_MS 30000U
#define OLED_LOCAL_URL_TIMEOUT_MS 20000U
#define OLED_QR_MAX_VERSION 4
#define OLED_QR_MAX_MODULES 33
#define OLED_QR_BITMAP_SIZE \
    ((OLED_QR_MAX_MODULES * OLED_QR_MAX_MODULES + 7) / 8)

#if CONFIG_REVLINK_STATUS_OLED_ROTATE_180
#define OLED_SEGMENT_REMAP_COMMAND 0xa0
#define OLED_COM_SCAN_COMMAND 0xc0
#else
#define OLED_SEGMENT_REMAP_COMMAND 0xa1
#define OLED_COM_SCAN_COMMAND 0xc8
#endif

static const char *TAG = "revlink_oled";
static spi_device_handle_t oled_spi;
static uint8_t framebuffer[OLED_BUFFER_SIZE];
static uint8_t previous_framebuffer[OLED_BUFFER_SIZE];
static revlink_status_model_t status_model;
static portMUX_TYPE status_lock = portMUX_INITIALIZER_UNLOCKED;
static bool oled_ready;
static bool hotspot_visible;
static char hotspot_ssid[20];
static char hotspot_password[16];
static bool hotspot_qr_visible;
static int64_t hotspot_qr_started_us;
static uint8_t hotspot_qr_size;
static uint8_t hotspot_qr_bitmap[OLED_QR_BITMAP_SIZE];
static bool local_url_visible;
static int64_t local_url_started_us;
static char local_url_hostname[64];
static char connected_network_ssid[OLED_CONNECTED_SSID_CAPACITY];
static revlink_oled_storage_state_t storage_display_state =
    REVLINK_OLED_STORAGE_NORMAL;
static uint32_t storage_format_seconds;

typedef struct {
    uint8_t size;
    uint8_t bitmap[OLED_QR_BITMAP_SIZE];
} hotspot_qr_render_t;


/*
 * The font and the primitives that draw with it live in revlink_oled_render,
 * where they can be rendered and inspected on a host. These bind them to this
 * module's framebuffer so the drawing code below reads as it always has.
 */
static void set_pixel(int x, int y, bool enabled)
{
    revlink_oled_set_pixel(framebuffer, x, y, enabled);
}

static void fill_rect(int x, int y, int width, int height, bool enabled)
{
    revlink_oled_fill_rect(framebuffer, x, y, width, height, enabled);
}

static void draw_rect(int x, int y, int width, int height)
{
    revlink_oled_draw_rect(framebuffer, x, y, width, height);
}

static int text_width(const char *text, int scale)
{
    return revlink_oled_text_width(text, scale);
}

static void draw_text(int x, int y, const char *text, int scale)
{
    revlink_oled_draw_text(framebuffer, x, y, text, scale);
}

static void draw_centered(int y, const char *text, int scale)
{
    revlink_oled_draw_centered(framebuffer, y, text, scale);
}

static void draw_splash(uint32_t elapsed_ms)
{
    const esp_app_desc_t *description = esp_app_get_description();
    revlink_oled_draw_splash(
        framebuffer,
        elapsed_ms,
        description != NULL ? description->version : NULL
    );
}

static void draw_wifi_icon(int x, int y)
{
    set_pixel(x, y + 2, true);
    set_pixel(x + 1, y + 1, true);
    fill_rect(x + 2, y, 3, 1, true);
    set_pixel(x + 5, y + 1, true);
    set_pixel(x + 6, y + 2, true);

    set_pixel(x + 1, y + 4, true);
    fill_rect(x + 2, y + 3, 3, 1, true);
    set_pixel(x + 5, y + 4, true);

    set_pixel(x + 3, y + 6, true);
}

static void draw_status(
    const revlink_status_view_t *view,
    uint32_t animation_tick,
    const char *network_badge
)
{
    memset(framebuffer, 0, sizeof(framebuffer));
    const uint32_t header_phase =
        animation_tick % OLED_HEADER_CYCLE_TICKS;
    const char *header =
        header_phase
                >= OLED_HEADER_CYCLE_TICKS - OLED_SIDECAR_WINDOW_TICKS
            ? "SIDECAR"
            : "REVLINK";
    draw_text(2, 3, header, 1);
    if (network_badge != NULL && network_badge[0] != '\0') {
        const int badge_text_width = text_width(network_badge, 1);
        const int badge_x = OLED_WIDTH - badge_text_width - 11;
        draw_wifi_icon(badge_x, 3);
        draw_text(badge_x + 9, 3, network_badge, 1);
    }
    fill_rect(2, 12, 124, 1, true);

    const int headline_scale = text_width(view->headline, 2) <= 124 ? 2 : 1;
    draw_centered(18, view->headline, headline_scale);
    char detail[24] = {0};
    const char *detail_text = view->detail;
    if (view->kind == REVLINK_STATUS_WIFI_RECONNECTING) {
        (void)snprintf(
            detail,
            sizeof(detail),
            "RETRY %u SEC",
            (unsigned int)view->countdown_seconds
        );
        detail_text = detail;
    }
    draw_centered(headline_scale == 2 ? 35 : 30, detail_text, 1);

    if (view->kind == REVLINK_STATUS_READY) {
        draw_centered(42, "READY", 2);
        draw_centered(57, "TO SYNC", 1);
        return;
    }

    if (view->show_progress) {
        draw_rect(8, 46, 112, 8);
        if (view->progress_indeterminate) {
            const int travel = 94;
            const int position = (int)(animation_tick % (uint32_t)(travel * 2));
            const int x = position <= travel ? position : travel * 2 - position;
            fill_rect(10 + x, 48, 16, 4, true);
        } else {
            const int width =
                (int)((uint32_t)view->progress_percent * 108U / 100U);
            fill_rect(10, 48, width, 4, true);
        }
        draw_centered(57, view->footer, 1);
        return;
    }

    draw_centered(51, view->footer, 1);
}

static void exact_copy(char *target, size_t capacity, const char *source);
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

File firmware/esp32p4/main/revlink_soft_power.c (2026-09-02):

#include "revlink_soft_power.h"

#include <stdbool.h>
#include <stdint.h>

#include "driver/gpio.h"
#include "esp_log.h"
#include "esp_sleep.h"
#include "esp_system.h"
#include "freertos/FreeRTOS.h"
#include "freertos/task.h"
#include "revlink_power_button.h"
#include "revlink_runtime.h"
#include "revlink_sd_storage.h"
#include "revlink_sidecar_identity.h"
#include "revlink_status_oled.h"
#include "revlink_storage_recovery.h"
#include "revlink_usb_link.h"
#include "revlink_wifi_radio.h"

#define REVLINK_BOOT_BUTTON_GPIO GPIO_NUM_35
#define REVLINK_BUTTON_SAMPLE_MS 25U
#define REVLINK_BUTTON_DEBOUNCE_MS 50U
#define REVLINK_BUTTON_HOLD_MS 2000U
#define REVLINK_SYNC_CANCEL_TIMEOUT_MS 30000U
#define REVLINK_MULTI_PRESS_WINDOW_MS 650U
#define REVLINK_QR_PRESS_COUNT 2U
#define REVLINK_LOCAL_SSID_CAPACITY 24U
#define REVLINK_LOCAL_HOSTNAME_CAPACITY 64U
#define REVLINK_STORAGE_CONFIRMATION_TIMEOUT_MS 20000U
#define REVLINK_STORAGE_RESULT_DISPLAY_MS 1500U

static const char *TAG = "revlink_power";
static bool task_started;

static void show_storage_step_one(revlink_sd_storage_state_t state)
{
    switch (state) {
    case REVLINK_SD_STORAGE_MISSING:
        revlink_status_oled_show_storage_error(
            REVLINK_OLED_STORAGE_MISSING
        );
        break;
    case REVLINK_SD_STORAGE_UNREADABLE:
        revlink_status_oled_show_storage_error(
            REVLINK_OLED_STORAGE_UNREADABLE
        );
        break;
    case REVLINK_SD_STORAGE_ERROR:
    case REVLINK_SD_STORAGE_UNKNOWN:
        revlink_status_oled_show_storage_error(
            REVLINK_OLED_STORAGE_ERROR
        );
        break;
    case REVLINK_SD_STORAGE_MOUNTED:
    default:
        break;
    }
}

static bool sync_is_active(revlink_sync_state_t state)
{
    return state == REVLINK_SYNC_QUEUED
        || state == REVLINK_SYNC_RUNNING
        || state == REVLINK_SYNC_CANCELLING;
}

static bool wait_for_sync_to_stop(void)
{
    uint32_t waited_ms = 0U;
    while (sync_is_active(revlink_runtime_sync_snapshot().state)) {
        if (waited_ms >= REVLINK_SYNC_CANCEL_TIMEOUT_MS) {
            return false;
        }
        vTaskDelay(pdMS_TO_TICKS(100U));
        waited_ms += 100U;
    }
    return true;
}

static void perform_shutdown(void)
{
    ESP_LOGW(
        TAG,
        "Soft shutdown requested; new syncs are now blocked"
    );
    const revlink_sync_coordinator_status_t prepare_status =
        revlink_runtime_prepare_shutdown();
    if (prepare_status != REVLINK_SYNC_COORDINATOR_OK) {
        ESP_LOGE(
            TAG,
            "Soft shutdown blocked while preparing runtime: status=%d",
            prepare_status
        );
        return;
    }

    if (!wait_for_sync_to_stop()) {
        ESP_LOGE(
            TAG,
            "Soft shutdown aborted: sync did not become quiescent within "
            "%u ms; reset or remove power only after activity stops",
            (unsigned int)REVLINK_SYNC_CANCEL_TIMEOUT_MS
        );
        return;
    }

    const esp_err_t usb_status = revlink_usb_link_disconnect();
    if (usb_status != ESP_OK) {
        ESP_LOGW(
            TAG,
            "Logical USB disconnect returned %s; continuing after the "
            "sync reached a terminal state",
            esp_err_to_name(usb_status)
        );
    }

    const esp_err_t storage_status = revlink_sd_storage_stop();
    if (storage_status != ESP_OK) {
        ESP_LOGE(
            TAG,
            "Soft shutdown aborted to protect storage: %s",
            esp_err_to_name(storage_status)
        );
        return;
    }

    ESP_LOGW(
        TAG,
        "microSD is cleanly unmounted; entering deep sleep. "
        "Wake by RESET or by cycling external power"
    );
    vTaskDelay(pdMS_TO_TICKS(100U));
    esp_deep_sleep_start();
}

static esp_err_t show_network_shortcut(void)
{
    const esp_err_t qr_status = revlink_status_oled_show_hotspot_qr();
    if (qr_status == ESP_OK) {
        return ESP_OK;
    }

    revlink_sidecar_identity_t identity = {0};
    const esp_err_t identity_status =
        revlink_sidecar_identity_snapshot(&identity);
    if (identity_status != ESP_OK) {
        return identity_status;
    }
    return revlink_status_oled_show_local_url(identity.hostname);
}

static void soft_power_task(void *context)
{
    (void)context;
    revlink_power_button_t button;
    const revlink_power_button_config_t config = {
        .debounce_ms = REVLINK_BUTTON_DEBOUNCE_MS,
        .shutdown_hold_ms = REVLINK_BUTTON_HOLD_MS,
    };
    if (!revlink_power_button_init(&button, &config)) {
        ESP_LOGE(TAG, "Unable to initialize power-button controller");
        vTaskDelete(NULL);
        return;
    }

    uint8_t short_press_count = 0U;
    uint32_t short_press_window_ms = 0U;
    const revlink_sd_storage_status_t initial_storage =
        revlink_sd_storage_status();
    revlink_storage_recovery_t storage_recovery;
    if (!revlink_storage_recovery_init(
            &storage_recovery,
            initial_storage.state == REVLINK_SD_STORAGE_UNREADABLE,
            REVLINK_STORAGE_CONFIRMATION_TIMEOUT_MS
        )) {
        ESP_LOGE(TAG, "Unable to initialize storage-recovery controller");
        vTaskDelete(NULL);
        return;
    }
    if (initial_storage.state != REVLINK_SD_STORAGE_MOUNTED) {
        show_storage_step_one(initial_storage.state);
    }

    while (true) {
        const bool pressed = gpio_get_level(REVLINK_BOOT_BUTTON_GPIO) == 0;
        const revlink_power_button_action_t action =
            revlink_power_button_update(
                &button,
                pressed,
                REVLINK_BUTTON_SAMPLE_MS
            );
        if (action == REVLINK_POWER_BUTTON_SHUTDOWN_REQUESTED) {
            short_press_count = 0U;
            short_press_window_ms = 0U;
            perform_shutdown();
        } else if (
            action == REVLINK_POWER_BUTTON_SHORT_PRESS_RELEASED
        ) {
            if (
                revlink_status_oled_hotspot_qr_visible()
                || revlink_status_oled_local_url_visible()
            ) {
                revlink_status_oled_hide_hotspot_qr();
                revlink_status_oled_hide_local_url();
                short_press_count = 0U;
                short_press_window_ms = 0U;
            } else {
                if (short_press_count < UINT8_MAX) {
                    ++short_press_count;
                }
                short_press_window_ms = 0U;
            }
        }
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

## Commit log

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2026-09-01 Stage a map without the AccessPort attached, apply it on the next sync
    A map arrives when it arrives — in the pits, in the driveway — and the car
    is not necessarily there. Requiring the AccessPort to be plugged in at that
    moment is an artificial constraint, so uploading and applying are now
    separate steps.
    POST /api/portal/maps/stage already accepted a map with no device attached,
    but the staged state was RAM-only and unattributed: it did not survive a
    power cycle, and nothing recorded which AccessPort it was meant for.
    Add firmware/components/revlink_staged_map, a platform-neutral component
    holding the two things that have to be right:
    - a fixed-size CRC-32 protected record carryin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
2026-09-01 Publish the flasher to GitHub Pages and restore automatic CI
    The repository is public now, so GitHub-hosted runners are free and there is
    no longer a reason to keep CI on manual dispatch.
    Pages can only serve a repository root or /docs when deploying from a branch,
    and the flasher lives at web/flash, so it is uploaded as an artifact instead.
    The deploy job runs the manifest and gate tests first: the page verifies every
    binary against manifest.json before writing to a board, and the same check
    should stop a bad artifact reaching Pages at all.
2026-09-01 Document the catalog in-repo and tighten the project's stated scope
    Two changes, both about not being read in bad faith.
    Remove every reference to a separate private catalog project. The part-number
    table is now documented where it lives, in docs/ACCESSPORT_CATALOG.md: what it
    is for (refusing to treat an unrecognised device as an AccessPort), where the
    data comes from (publicly published product identifiers), what it explicitly
    does not contain, and how to add a part. The compiled revision string becomes
    revlink-catalog-2026-07-28, so binaries are rebuilt and republished.
    Remove the map-decoding roadmap from docs/VEHICLE_HEALTH.md. It described
    decoding protected map content, reading ../a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
2026-09-01 Add a landing page, and make a failed flash retryable
    The site now has a front door at / and the flasher at /flash/. Dropping a
    stranger straight onto a Connect button asked them to act before they knew
    what the thing was. The landing page is deliberately thin — pitch, photos,
    what it does, what it deliberately does not do, what you need, where it
    stands — so it does not drift out of step with the README, which stays the
    detailed document.
    Photos are downscaled from the originals and re-encoded, which also strips
    camera metadata; verified no GPS, maker note, or device model survives.
    Flasher changes prompted by a write that died partway with the board still
    attached:
    - Fix a real bu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
2026-09-01 Report flash progress honestly, and name the real cause of a stalled write
    A field log showed a write failing at 81% while the page's bar read about
    30%. Both numbers were about the same moment; the bar was wrong.
    With compression enabled, esptool reports bytes of the compressed stream,
    whose size is not known until each part begins. The bar divided those
    compressed bytes by the uncompressed total, so it always read low and made a
    late failure look like an early one. Track each part's own completion
    fraction and weight it by uncompressed size instead. Checked against the
    numbers from that log: the bar now reads 81% where it previously read 43%.
    The failure itself was the serial link, not t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
2026-09-01 Erase before writing, so a long erase cannot stall the write
    A second field log ruled out the transfer rate. At 115200 the write failed at
    the same block, at the same address, as it had at 460800:
    Failed to write compressed data to flash after seq 35 failed with
    status 201,0
    A marginal link fails at random points. Failing twice at seq 35 and 0x17f20d,
    at rates a factor of four apart, means whatever goes wrong does not depend on
    how fast bytes move.
    Reading the loader confirms it. That message is not the device reporting
    error 201; it comes from the branch taken when a response arrives SHORTER
    than expected, and 201,0 is simply the first two bytes of a truncated reply:
    if (n && n[1]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
2026-09-01 Pass firmware to esptool-js as bytes, not as a binary string
    Flashing failed at the same block on every attempt. Neither of my first two
    explanations was right, and the numbers said so:
    native esptool compressed 1359040 -> 649050, hash verified, board boots
    esptool-js compressed 1359040 -> 720430, failed at seq 35
    Identical input cannot compress 11% worse. esptool-js was not being given the
    same bytes.
    esptool-js 0.6 declares fileArray as { data: Uint8Array; address: number }.
    This code passed a latin1 "binary string", which was the API before 0.5. The
    deflate step then encoded that string as UTF-8, so every byte above 0x7F
    became two, and the device was sent a stream longer t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
2026-09-01 Publish the full build, and raise two task stacks chasing a reboot
    Publish the Nano product profile instead of the read-only one. Writing a .ptm
    onto the AccessPort's own storage is not the same as putting a calibration
    into an engine: installing a map remains a deliberate action taken on the
    AccessPort itself, and nothing here can flash an ECU or trigger that install.
    The plausible failure is a damaged file or a confused maps/ directory, which
    is a device problem, not a vehicle one. Writes still arrive locked behind
    owner consent, still accept only maps/*.ptm, and are still read back and
    checked against their SHA-256. SAFETY.md now draws that distinction instead
    of treating every write as a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
2026-09-01 Give the HTTP server task enough stack to serve the portal
    The board rebooted every few tens of seconds with a stack protection fault.
    Catching the full panic rather than only the fact of it named the culprit:
    Detected in task "
    Accept-<garbage>" at 0x400b16be
    Stack pointer: 0x4ff4e000
    Stack bounds: 0x4ff4e00c - 0x4ff4f800
    The task name is not a task name. T5 and T6 held 0x6363410a and 0x2d747065 —
    "\nAcc" and "ept-" — so an Accept- header had been written over the task
    control block, and the stack pointer sat below its own lower bound. Those
    bounds span 0x17F4, which is the 6144-byte stack configured for the HTTP
    server in revlink_onboarding.c.
    One listener serves the ten onb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
2026-09-01 Take the backup export's 8 KiB of buffers off the stack, and say it is broken
    Clicking "download backup" took the board down. walk_export() recurses to
    BACKUP_MAX_DEPTH, which is 10, carrying child_absolute[384], child_relative
    [256] and a struct stat per level; at the leaf export_one() holds a 4 KiB
    transfer buffer while the hash_stream() it calls holds another. Roughly
    7.5 KiB of recursion under 8 KiB of buffers is past any stack this HTTP
    server can reasonably be given, whatever it is set to.
    Both 4 KiB buffers now come from the heap.
    That stopped the panic — ten consecutive backup requests produced no Guru
    Meditation where before it faulted — but it did not make backup work. The
    re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
2026-09-01 Record staged-map persistence as accepted on hardware
    A map saved with no AccessPort attached survived a power cycle on the
    reference Nano and came back intact:
    Restored staged map 'maps/<name>.ptm' (58885 bytes) pinned to part=AP3-SUB-004
    That exercises the whole persistence path — metadata written atomically beside
    the payload, decoded at boot, destination re-validated against the current
    write policy, payload re-hashed and matched against its recorded SHA-256, and
    the device pin preserved. Anything that failed those checks would have been
    discarded rather than carried forward, so a restore appearing at all is the
    check passing.
    Staging, persistence and the pin move to the accepted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
2026-09-01 Stop calling map writes unproven — they are not
    SAFETY.md listed "live map upload round-trip against a device" as not
    accepted on hardware, and the flasher page, the portal, and STAGED_MAPS.md
    all repeated it. docs/MAP_WRITE_ACCEPTANCE.md, sitting in the same directory,
    says otherwise:
    During the first live pass the AccessPort accepted the file ... a
    subsequent read-only session recovered the exact uploaded bytes and digest.
    The only failure in that pass was local: the cache's path validator rejected
    spaces in map names and reported a misleading ESP_ERR_INVALID_CRC after the
    transfer had already completed. Validators now accept safe spaces and
    parentheses, with host tests covering th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
2026-09-01 Apply a staged map when the device is ready, not when the sync ends
    Auto-apply fired and the write failed with platform error 259,
    ESP_ERR_INVALID_STATE. Every gate had passed — staged, pinned, consent on,
    serials matching AP3-SUB-004, sync completed with nothing pending — so the
    refusal came from the transport, and the reason is in the USB worker:
    if (selected == NULL) { ... upload_observe(..., ESP_ERR_INVALID_STATE, ...)
    It holds no eligible device handle at that moment. A clean sync ends with a
    polite session close, and that close triggers a software re-enumeration; the
    write was being started inside exactly that window. Hooking it to
    REVLINK_SYNC_EVENT_COMPLETED meant firing duri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
2026-09-01 Clear a staged map once it has been written, and let the owner discard one
    The portal kept saying a map would be transferred after it already had.
    observe_upload() recorded the outcome but never cleared the staging, so
    `staged` stayed true through a verified write and survived the next reboot.
    That was not only cosmetic. With auto-apply on, the next clean sync offered
    the same map again and the device refused it as an existing destination,
    leaving state=failed on a transfer that had in fact succeeded. Observed on
    hardware before this change.
    A verified write now discards the payload: it reached the device and read
    back byte-for-byte, so nothing is pending. A failed write deliberately keeps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
2026-09-01 Refuse a map name the AccessPort already has, at staging
    Tested against the board with a byte-identical copy of a map already on the
    device, staged under its own name. Staging accepted it without comment,
    auto-apply then started the transfer, and the device refused it:
    Applying staged map 'maps/Ray 2016 DYNOTUNE.ptm' to pinned AccessPort
    MAP WRITE FAILED: ready/completion/readback=failed
    staged=true state=failed err=259
    An AccessPort never overwrites a map, and it says so at the readiness step —
    after a transfer has begun and the write service has entered its running
    state. So a name that could never have worked produced a started transfer, a
    generic failure, and a staged payload l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
2026-09-01 Fix a toast that read "Saved for undefined"
    stageMap() reported the pinned device from upload.target. Status emits
    targetPartNumber. The notice beside it already used the right key, so the
    staged map displayed correctly while the toast confirming it said undefined.
    Only surfaced by driving the portal itself. Every API-level test passed
    throughout, because the wrong key was read from a response the API tests
    never rendered.
    Full flow exercised through the UI against the board: save with a file on the
    input, staged notice naming AP3-SUB-004, transfer, read-back verified and the
    staging cleared, an identical duplicate passing quietly, a one-byte-different
    duplicate refused, and discard return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
2026-09-02 Add the 0x1625 delete builder and its allowlist, nothing that can call them
    First layer of AccessPort delete. Deliberately inert: no transport request
    kind, no service, no endpoint, so nothing in the firmware can reach these yet.
    revlink_ap_build_delete() emits the capture-verified 0x1625 record. Its body
    is byte-identical to a 0x1620 download and the device separates them by opcode
    alone, so it is a separate function rather than a flag on the download
    builder — a read path must not be able to produce a delete by mistake.
    revlink_ap_validate_delete_target() is narrower than the protocol allows: one
    file directly inside maps/ or datalog/, nothing else. Not images/, not the
    directories the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
2026-09-02 Ask contributors to open an issue before multi-layer work
    This project's features routinely span protocol, transport, service and
    portal, and it is easy to land one layer and lose track of the rest. Staged
    maps shipped complete in firmware with no UI at all, and the docs described
    something only reachable by curl; delete has been solved and proven on
    another platform for months without anyone noticing the Sidecar had no path
    to it.
    Tracking the work makes the missing layers visible, which matters more here
    than usual: a half-implemented device-facing feature is worse than none.
    Delete is now tracked as #1.
2026-09-02 Add the delete transport, behind a default-off compile flag (#1)
    Second layer of AccessPort delete. Still unreachable from the portal: there is
    no service and no endpoint, and CONFIG_REVLINK_ALLOW_DEVICE_DELETES defaults
    to n, so no published image carries any of it.
    The ack gap the issue identified is closed first.
    revlink_ap_is_plain_ack_payload() validates a class-0x01 mini against a
    multi-byte payload; the existing single-byte helper cannot express delete's
    two-byte ASCII "15", and a test asserts it still refuses one.
    run_file_delete() mirrors run_map_upload()'s scaffolding rather than inventing
    its own: interface claim, session events, polite disconnect, identical
    cleanup. On top of t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
    [revlink_accessport_usb.h]
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2026-09-02 Add the delete endpoint and portal controls (#1)
    Fourth and last code layer. CONFIG_REVLINK_ALLOW_DEVICE_DELETES is still
    POST /api/portal/file/delete takes the path in a header and refuses unless the
    attached AccessPort is also the dataset on screen. Deleting from a device
    other than the one being looked at is the mistake most worth preventing, and
    the check costs nothing. POST /api/portal/deletes carries the consent, kept
    apart from write consent at every layer including this one.
    Status now reports deleteConsent, deleteState and deleteError. An unreadable
    delete snapshot reads as locked, never as permitted.
    In the portal, rows grow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
2026-09-02 Document deletion, and correct a README that described an old release
    docs/FILE_DELETE.md covers what can be deleted, what happens on the wire, why
    the gates are separate from writes, and that the Sidecar's cached copy
    deliberately outlives the file. SAFETY.md lists deletion as gated and
    compiled out of published images, and records the hardware acceptance.
    The README had drifted from what is actually published:
    - it still called the published image read-only with map upload compiled
    out. That stopped being true when the release moved to the Nano profile;
    - it described map writes as sitting behind a compile-time flag, which they
    no longer do in a published build — consent is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
2026-09-02 Republish the flasher image from main
    The published binaries predated the delete work, so the site and the
    repository disagreed about what a Sidecar runs. Nothing user-facing differed —
    deletion is compiled out either way — but that gap is exactly the drift that
    produced a README describing an older release, and it is not worth carrying.
    The rebuilt image is still the deletes-off profile. It carries the delete
    endpoints, which answer 501 Not Implemented, so the API keeps one shape
    regardless of how an image was built and a portal does not have to guess
    which routes exist. None of the implementation is present: no transport, no
    service, no audit log.
    Verified before publishing: no delet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
2026-09-02 Restart the board after a web flash, and name the build on the splash
    Two things field testing turned up, plus the Windows result.
    The board had to be power cycled by hand after every browser flash, on every
    operating system. esptool-js only resets when ESPLoader was constructed with
    resetConstructors; without them after("hard_reset") matches its case, finds no
    constructor, and returns having done nothing. No error, no log line — which is
    why this looked like the board ignoring a reset rather than a reset never
    being attempted. Native esptool resets the same hardware fine, and that should
    have been the clue. Pass the constructors and ask for the reset explicitly.
    Nothing can be shown on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
    [revlink_status_oled.c]
2026-09-02 Drive the reset pulse instead of trusting esptool-js to do it
    Passing resetConstructors was necessary but not sufficient: the board still
    sat in the bootloader after a browser flash. HardReset does only this:
    async reset() { await delay(100); await this.transport.setRTS(false) }
    It lowers RTS and nothing else, assuming RTS is currently high and holding the
    chip in reset. esptool-js's own connect sequence ends with RTS already low, so
    on this board the call changes no signal at all — there is no pulse, and the
    chip is never restarted. It fails silently either way, which is why the first
    fix looked plausible and changed nothing.
    Drive the whole sequence instead, using Transport's docume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
2026-09-02 Make each published build name one set of bytes, and report its commit
    Four different binaries were published today all calling themselves 0.2.0,
    because releases were being written over in place. A version that names more
    than one set of bytes is worse than no version: a report against 0.2.0 cannot
    be resolved, and two boards said to be running it cannot be compared.
    Release directories are immutable now. Publishing adds firmware/<version>-
    <profile>/ and moves the pointer in releases.json, which both the page and the
    tests read, so a release is named once. Older releases stay reachable for
    anyone who needs to go back to a build that worked. The v0.2.0 directory is
    removed rather than kept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
2026-09-02 Release the serial port after a write, which is what restarts the board
    The signal pulse ran and reported success, and the board still sat in the
    bootloader. Testing the same sequence over a plain serial port on the same
    hardware resets it reliably — pulse RTS on an open port, boot banner follows —
    so the sequence is right and the hardware honours it. Through Web Serial it
    evidently does not reach the pins, and nothing throws to say so, which is why
    two rounds of fixing the pulse changed nothing.
    Native esptool ends by closing the port. Closing drops the control lines to
    their idle state and resets the board; confirmed on a real Nano. The page held
    the port open after writing, so that n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
2026-09-02 Move the restore path's transfer buffers off the HTTP task stack (#3)
    validate_pending(), skip_bytes() and revlink_backup_restore_merge() each held
    a 4 KiB array on the stack, on the same HTTP server task whose export
    equivalents had to be moved to the heap after a stack-protection fault. The
    worst case was not 4 KiB but 8: restore_merge() calls skip_bytes() from inside
    its loop while its own buffer is still live, so both frames coexist — against a
    12 KiB stack that was itself raised from 6 KiB after a measured 6116-byte peak
    overflowed it.
    Restore has never been exercised on hardware, so this was recorded as latent
    rather than as a bug. It was still the same arithmetic that already overf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
2026-09-02 Tell a cached file from one the AccessPort no longer has (#2)
    The Sidecar keeps its own copy of everything it syncs, and a delete does not
    touch that. So after a delete the row stayed in the portal — correctly, the
    Sidecar does still have the file — but nothing distinguished that from a file
    still sitting on the device. The portal kept offering Delete, which then failed
    with ESP_ERR_NOT_FOUND, and a file removed with COBB's own software would have
    gone on being listed as though it were there.
    Presence is tracked as three states, not two. "We did not see it" and "it is
    not there" are different claims and only one of them is evidence: a listing
    that was cancelled, failed, or never taken s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
    [revlink_accessport_usb.h]
2026-09-02 Compile deletion into the shipped Nano build, and cut 0.2.2
    Deletion has been built, tested on hardware, and compiled out of every
    published image since. Without a computer a full AccessPort cannot be cleared,
    and that is one of the two things the Sidecar exists to fix, so shipping the
    capability but not the code left the feature theoretical.
    Compiling it in is not enabling it. Delete consent is a separate runtime switch
    from write consent, starts locked, is never implied by agreeing to map
    transfers, and survives only until the owner turns it off. Only files directly
    inside maps/ and datalog/ can be removed — not images/, not the directories
    themselves, nothing nested. Every delete pins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
2026-09-02 Publish 0.2.2, and correct the docs that said deletion was compiled out
    The release directory, the manifest, SHA256SUMS and the releases.json pointer
    for v0.2.2-nano, built from 119660ff. v0.2.1 stays where it is and stays
    reachable.
    Several places asserted that published images contain no delete code. They
    did, and that was true until this build; leaving it would have been the worst
    kind of stale safety documentation — reassuring and wrong. README, SAFETY.md,
    FILE_DELETE.md, the flasher page and the portal's own settings copy now say
    what the shipped image actually does, and say the part that matters: the
    capability being present is not the capability being on.
    The manifest gains device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
2026-09-02 Correct the record: map writing is proven on hardware and is in the build
    The landing page said writing maps "has not been proven on hardware, which is
    exactly why it isn't in the published build". Both halves were false. Writes
    have been compiled into the published Nano profile since 0.2.1, and SAFETY.md's
    own accepted list has recorded a verified hardware write for longer than that —
    the page was contradicting a document in the same repository. In practice the
    maintainer has been transferring maps to a device in service, several different
    ones, each read back and matched by SHA-256 before being reported as done.
    Documentation that understates what the software does is not caution. It is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
2026-09-02 Give the two sync status enums names that say which layer they belong to (#4)
    revlink_sync_manifest.h and revlink_sync_coordinator.h both defined a
    revlink_sync_status_t, and both defined REVLINK_SYNC_OK and
    REVLINK_SYNC_INVALID_ARGUMENT — with different meanings. The typedef was only
    half of it; the enumerators collided too.
    Nothing in the tree included both, so it never broke a build. It broke the
    next person to write an ordinary include, and the error blamed the header
    rather than the collision. I lost time to it adding a presence field to the
    portal projection and worked around it instead of fixing it.
    Both are renamed, not just one. Leaving either as REVLINK_SYNC_OK would keep
    the q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
    [revlink_soft_power.c]
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
